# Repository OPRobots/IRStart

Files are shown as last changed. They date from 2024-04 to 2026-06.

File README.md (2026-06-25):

# IRStart

Mando y módulo para el arranque de nuestros robots usando el protocolo RC5.
Basado en: https://p1r.se/startmodule/ por lo que lo hemos hecho compatible
y con un funcionamiento muy similar para que sea apto para competir en la
RoboChallenge de Rumania.

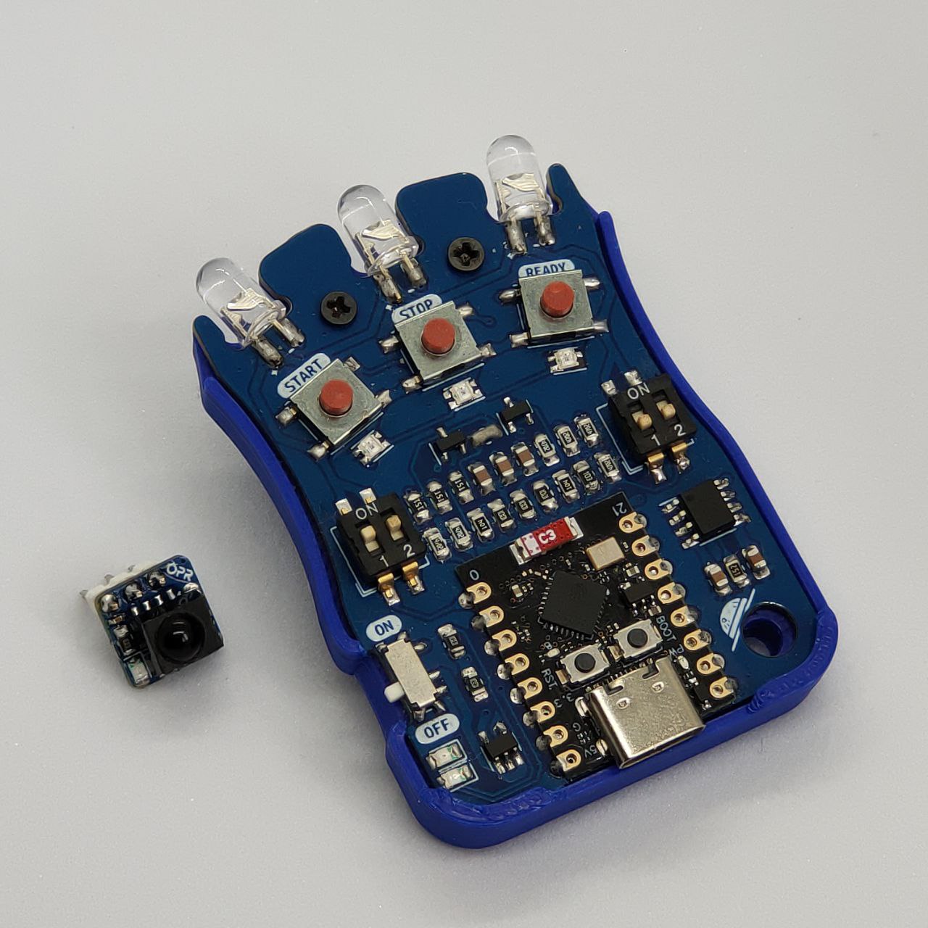
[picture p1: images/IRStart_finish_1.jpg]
IRStart - Diseño módulo


## ⚙️ Hardware

### Módulo
- ATTiny13 SMD SOIC-8
- Receptor IR TSOP4838
- LED azul SMD 0804
- 1 resistencia 220 Ω SMD 0804
- 1 condensador 104 (100 nF) SMD 0402

### Mando
- ESP32 C3 Super Mini
- 3 LEDs IR con MOSFETs (Start/Stop alta intensidad, Ready baja intensidad)
- DIP switch ×4 para configuración de robot (ID)
- NeoPixel RGB ×3 para indicación de estado
- Botones: Start, Stop, Ready, Mode
- Interruptor de encendido
- Módulo de carga de batería LiPo
- Batería LiPo 1S 500 mAh

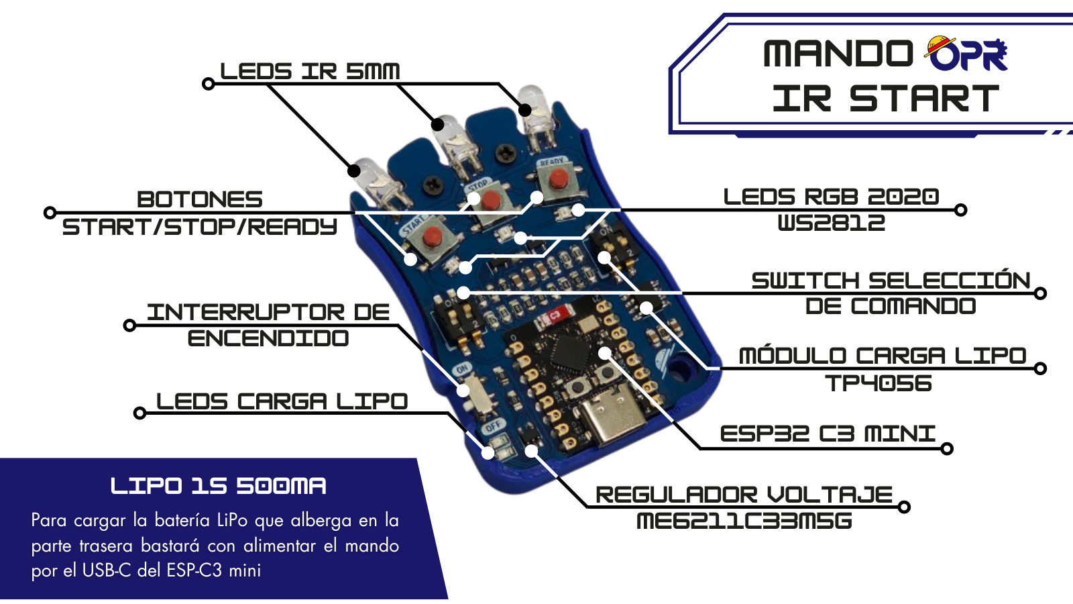
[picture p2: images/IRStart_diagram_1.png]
IRStart - Mando


## 💻 Software

- Programado con PlatformIO (Arduino framework)
- Firmware para módulo (ATtiny13/ATtiny85) y mando (ESP32-C3)
- **Protocolos IR**: RC5, NEC, SIRC
- **Modos**: IRSTART (competición) + IRMENU (control de menú remoto)
- **Frecuencia portadora**: 36 kHz (RC5) / 37 kHz (NEC, SIRC)
- **Debug**: Serial 115200 baud + patrones LED

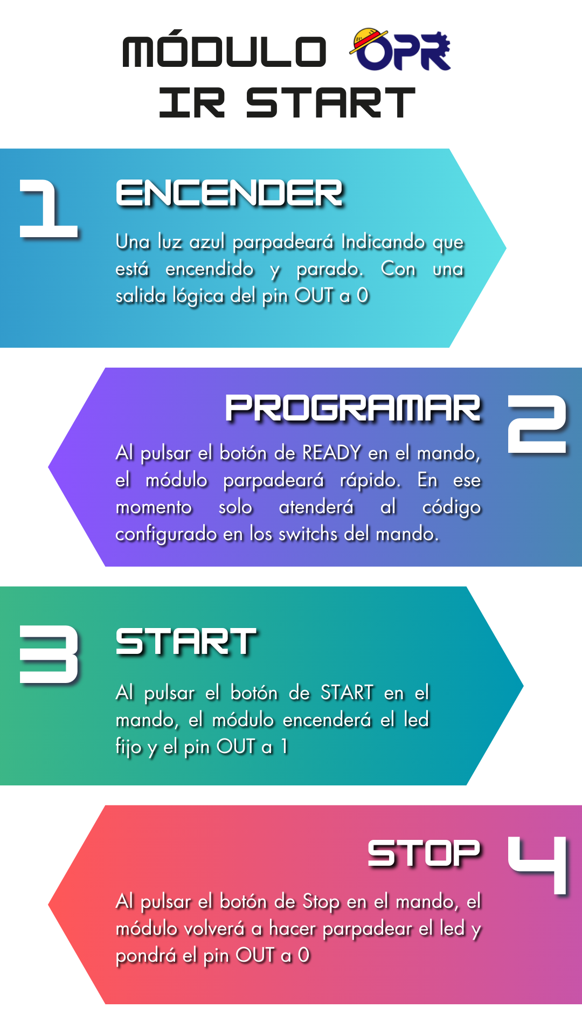
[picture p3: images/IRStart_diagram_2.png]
IRStart - Módulo


## 📚 Documentación

- [Hardware](docs/01-hardware.md) — MCUs, pinout, componentes, diseño 3D
- [Arquitectura Software](docs/02-software-architecture.md) — Bucles, ISRs, máquinas de estado
- [Protocolos IR](docs/03-ir-protocols.md) — RC5, NEC, SIRC: codificación y timing
- [Menú](docs/04-menu-system.md) — Modo IRMENU y navegación remota
- [Debug](docs/05-debug-system.md) — Salida serie y patrones LED
- [EEPROM](docs/06-storage.md) — EEPROM del ATtiny
- [Problemas Conocidos](docs/07-known-issues.md) — 10 issues (3 críticos)

## 🔧 Stack Tecnológico

| Componente | Tecnología |
|---|---|
| **Mando MCU** | ESP32-C3 (RISC-V 160 MHz) |
| **Módulo MCU** | ATtiny13/85 (AVR 8-bit) |
| **Framework** | Arduino |
| **Entorno** | PlatformIO |
| **Lenguaje** | C++11 |
| **Protocolos** | RC5, NEC, SIRC |

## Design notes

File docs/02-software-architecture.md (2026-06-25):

# Arquitectura Software

El sistema IRStart tiene dos arquitecturas independientes: el **mando**
(Remote, ESP32-C3) que emite códigos IR, y el **módulo** (Module,
ATtiny13/85) que los recibe y controla la señal de arranque/parada.

---

## Mando (Remote — ESP32-C3)

### Bucle Principal

```mermaid
flowchart TD
    A[Boot] --> B[init_components]
    B --> C{¿Botón pulsado en boot?}
    C -->|Start| D[Protocolo = RC5]
    C -->|Stop| E[Protocolo = NEC]
    C -->|Ready| F[Protocolo = SIRC]
    C -->|Ninguno| G[Protocolo = RC5 default]
    D --> H[init_ir]
    E --> H
    F --> H
    G --> H
    H --> I[Esperar liberación de botones]
    I --> J[Mostrar LEDs modo]
    J --> K[Loop]
    K --> L{¿Botón Ready?}
    L -->|Sí| M[Enviar Ready]
    L -->|No| N{¿Botón Start?}
    N -->|Sí| O[Enviar Start]
    N -->|No| P{¿Botón Stop?}
    P -->|Sí| Q[Enviar Stop]
    P -->|No| R{¿Botón Mode?}
    R -->|Sí| S[Cambiar modo]
    R -->|No| T[Actualizar LEDs según modo]
    M --> T
    O --> T
    Q --> T
    S --> T
    T --> K
```

### Secuencia de Boot

1. `init_components()` configura todos los pines (GPIO, NeoPixel, Serial)
2. Se detecta qué botón está pulsado al encender para seleccionar el protocolo
3. Se inicializa el protocolo IR con `init_ir()`
4. Se espera a que el usuario suelte todos los botones (LED parpadea)
5. Se muestran los colores de modo en los NeoPixels y se entra al bucle

| Protocolo | Botón en boot | Color Ready | Color Start | Color Stop |
|---|---|---|---|---|
| **RC5** | Start | Rojo | Verde | Azul |
| **NEC** | Stop | Rojo | Verde | Azul |
| **SIRC** | Ready | Rojo | Verde | Azul |

### Sistema de Modos

El mando tiene dos modos de operación:

| Modo | ID | Botón Start | Botón Stop | Botón Ready |
|---|----|---|---|---|
| **IRSTART** | 0 | Envía Start | Envía Stop | Prog/Ready |
| **IRMENU** | 1 | Menú Arriba | Menú Abajo | Menú Modo |

El cambio de modo se realiza con el botón Mode (GPIO 6) y es cíclico:
`(modo_actual + 1) % NUM_MODES`.

### Envío de comandos

Cada protocolo implementa su propia inicialización y funciones de envío:

| Función | RC5 | NEC | SIRC |
|---|-----|-----|---|
| **Init** | `rc5_init()` | `nec_init()` | `sirc_init()` |
| **Ready** | `rc5_send_prog()` | `nec_send_ready()` | `sirc_send_ready()` |
| **Start** | `rc5_send_start()` | `nec_send_start()` | `sirc_send_start()` |
| **Stop** | `rc5_send_stop()` | `nec_send_stop()` | `sirc_send_stop()` |

### Sistema de entrada

Todos los botones usan un debounce por software de 10 ms con doble lectura:

```cpp
bool get_btn_start() {
    bool state1 = digitalRead(BTN_START);
    delay(10);
    bool state2 = digitalRead(BTN_START);
    return state1 && state2;
}
```

El DIP switch de 4 posiciones se lee como un valor de 4 bits, desplazado 1
bit a la izquierda (`<< 1`), generando un ID de robot par entre 0 y 30.

---

## Módulo (Module — ATtiny13/85)

### Bucle Principal

```mermaid
flowchart TD
    A[Boot] --> B[init_pinout]
    B --> C[rc5_init]
    C --> D[Loop]
    D --> E{¿module_is_started?}
    E -->|Sí| F[LED ON fijo]
    E -->|No| G[LED parpadeando]
    F --> D
    G --> D
```

### ISR del Receptor IR

El módulo opera enteramente por interrupciones. El pin `PIN_IR` (PB1) se
configura con `attachInterrupt(CHANGE)` para detectar cada flanco (subida
y bajada) de la señal del TSOP4838.

| Parámetro | Valor |
|---|---|
| **Pin** | PB1 (digitalPinToInterrupt) |
| **Modo** | CHANGE (flanco de subida y bajada) |
| **ISR** | `rc5_isr()` |

### Cadena de procesamiento RC5

```
TSOP4838 → PIN_IR (CHANGE INT) → rc5_isr() → rc5_register() → rc5_decode_pulse()
    → rc5_decode_event() → (14 bits) → rc5_manage_command()
```

1. **`rc5_isr()`**: Lee el estado del pin IR y llama a `rc5_register()` con el
   trigger (RISING/FALLING)
2. **`rc5_register()`**: Calcula el tiempo transcurrido desde el último flanco
   y llama a `rc5_decode_pulse()` con ese `elapsed`. Incluye un
   `delayMicroseconds(100)` tras el cálculo
3. **`rc5_decode_pulse()`**: Clasifica el pulso como corto o largo según las
   constantes de timing, y llama a `rc5_decode_event()`
4. **`rc5_decode_event()`**: Máquina de estados de 4 estados para decodificar
   el código Manchester del protocolo RC5
5. **`rc5_manage_command()`**: Cuando se completan 14 bits, procesa el comando:
   - **Address PROG (0x0B)**: Programa un nuevo código de start/stop
   - **Address COMP (0x07)**: Compara con el código almacenado y ejecuta
   - **Default**: Comandos fijos 0x01 (start) y 0x02 (stop)

### Máquina de Estados RC5 (Receptor)

```mermaid
stateDiagram-v2
    [*] --> STATE_MID1
    STATE_MID1 --> STATE_MID0 : short space / long space
    STATE_MID0 --> STATE_MID0 : short pulse / long pulse
    STATE_MID0 --> STATE_MID1 : short space
    STATE_MID1 --> STATE_MID1 : long space / short pulse
    STATE_MID1 --> STATE_START1 : long pulse
    STATE_START1 --> STATE_MID0 : short space / long space
    STATE_START1 --> STATE_START0 : short pulse
    STATE_START0 --> STATE_START0 : long pulse / short pulse
    STATE_START0 --> STATE_MID1 : long space
```

> Basado en la implementación de [p1r.se/startmodule](https://p1r.se/startmodule/) con la información de [SB-Projects RC5 Protocol](https://www.sbprojects.net/knowledge/ir/rc5.php).

### Control de señal

| Función | Efecto |
|---|---|
| `module_start()` | `PIN_SIGNAL = HIGH`, `PIN_LED = HIGH`, `started = true` |
| `module_stop()` | `PIN_SIGNAL = LOW`, `PIN_LED = LOW`, `started = false` |
| `module_feedback()` | 5 parpadeos LED acelerados + pausa de 1.5 s |

El pin `PIN_SIGNAL` (PB0) es la salida física hacia el robot, y el LED (PB4)
refleja el estado de la señal.

---

## Compilación condicional

| Macro | Función |
|---|---|
| `PIO_FRAMEWORK_ARDUINO_ENABLE_CDC` | Habilita CDC Serial en ESP32-C3 (Remote) |

---

*Documento generado el 2025-06-25. Ver también [Hardware](01-hardware.md), [Protocolos IR](03-ir-protocols.md), [Problemas Conocidos](07-known-issues.md).*

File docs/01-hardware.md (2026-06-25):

# Hardware

El sistema IRStart se compone de dos dispositivos independientes: un **mando**
(Remote) basado en ESP32-C3 que emite señales infrarrojas con múltiples
protocolos, y un **módulo** (Module) basado en ATtiny que las recibe y actúa
como señal de arranque/parada para robots de competición.

---

## Mando (Remote)

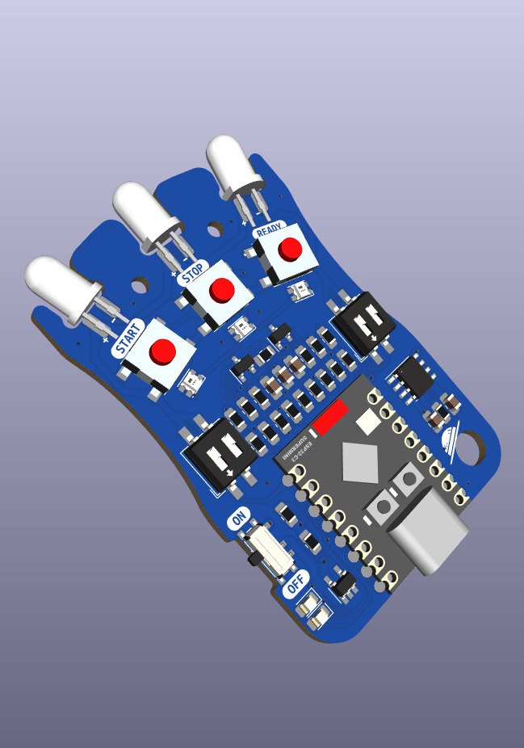
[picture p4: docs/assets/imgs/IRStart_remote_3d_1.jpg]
Remote 3D Model


### Microcontrolador

| Característica | Detalle |
|---|---|
| **Modelo** | Seeed XIAO ESP32C3 |
| **MCU** | ESP32-C3 (RISC-V 32 bits) |
| **Frecuencia** | 160 MHz |
| **Flash** | 4 MB |
| **RAM** | 400 KB SRAM |
| **Framework** | Arduino (ESP32 Core) |
| **Entorno** | PlatformIO |

### Componentes

| Componente | Modelo / Especificación | Cantidad |
|---|---|---|
| **LED IR (alta intensidad)** | MOSFET para Start/Stop | 2 |
| **LED IR (baja intensidad)** | MOSFET para Ready | 1 |
| **LED RGB** | NeoPixel WS2812B (×3) | 1 tira |
| **LED indicador** | LED onboard | 1 |
| **Botón Start** | Pulsador táctil | 1 |
| **Botón Stop** | Pulsador táctil | 1 |
| **Botón Ready** | Pulsador táctil | 1 |
| **Botón Modo** | Pulsador táctil | 1 |
| **DIP Switch** | 4 posiciones | 1 |
| **Interruptor** | Encendido principal | 1 |
| **Cargador de batería** | Módulo carga LiPo 1S | 1 |
| **Batería** | LiPo 1S 500 mAh | 1 |

### Pinout

| Pin | Periférico | Función |
|-----|---|---|
| **GPIO 8** | LED | LED indicador onboard |
| **GPIO 5** | NeoPixel | Tira de 3 LEDs RGB |
| **GPIO 2** | BAT_ANALOG | Lectura de batería (definido, sin usar) |
| **GPIO 4** | IR_CMD / LEDC Ch.0 | LED IR de comandos (Start/Stop) |
| **GPIO 7** | IR_PROG / LEDC Ch.1 | LED IR de programación (Ready) |
| **GPIO 21** | BTN_START | Botón de inicio |
| **GPIO 20** | BTN_STOP | Botón de parada |
| **GPIO 10** | BTN_READY | Botón de preparado |
| **GPIO 6** | BTN_MODE | Botón de cambio de modo |
| **GPIO 0** | DIP_SW_0 | DIP switch bit 0 (LSB) |
| **GPIO 1** | DIP_SW_1 | DIP switch bit 1 |
| **GPIO 2** | DIP_SW_2 | DIP switch bit 2 |
| **GPIO 3** | DIP_SW_3 | DIP switch bit 3 (MSB) |

> **Nota**: Los pines de los DIP switches usan GPIO 0–3. GPIO 2 está compartido
> con `BAT_ANALOG`, pero la funcionalidad de lectura de batería no está
> implementada.

### LEDs IR y MOSFETs

El mando utiliza dos canales PWM independientes para los LEDs infrarrojos:

| Canal | GPIO | LEDC Ch. | Propósito | Intensidad |
|---|---|---|---|---|
| **CMD** | GPIO 4 | 0 | Start / Stop | Alta (MOSFET dedicado) |
| **PROG** | GPIO 7 | 1 | Ready / Programación | Baja (MOSFET dedicado) |

Cada canal se configura con PWM de 10 bits de resolución. La frecuencia
portadora varía según el protocolo: **36 kHz** para RC5 y **37–40 kHz** para
NEC y SIRC.

---

## Módulo (Module)

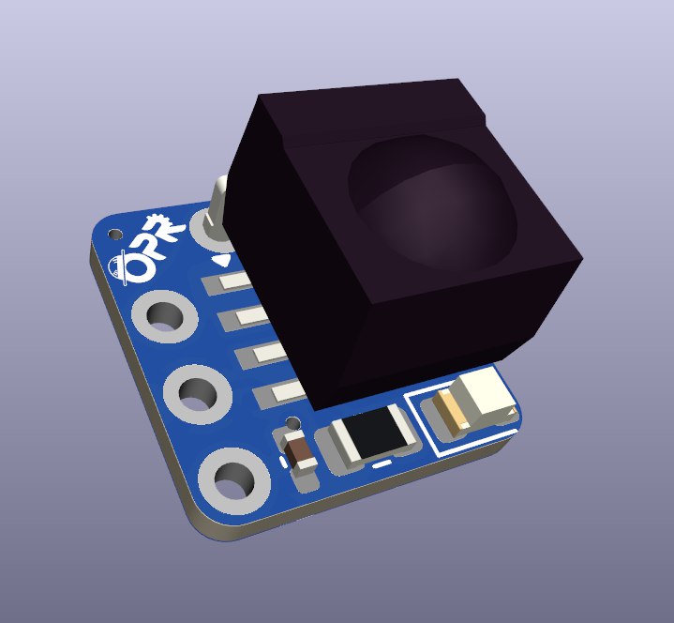
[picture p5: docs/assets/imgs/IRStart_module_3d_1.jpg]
Module 3D Model


### Microcontrolador

| Característica | Detalle |
|---|---|
| **Modelo** | ATtiny13 / ATtiny85 |
| **Arquitectura** | AVR 8 bits |
| **Frecuencia** | 1.2 MHz (default) / 9.6 MHz (internal) |
| **Flash** | 1 KB (ATtiny13) / 8 KB (ATtiny85) |
| **RAM** | 64 B (ATtiny13) / 512 B (ATtiny85) |
| **EEPROM** | 64 B (ATtiny13) / 512 B (ATtiny85) |
| **Framework** | Arduino (ATTinyCore) |
| **Entorno** | PlatformIO |

El `platformio.ini` soporta tanto **ATtiny13** como **ATtiny85**, con entornos
de programación directa y vía ArduinoISP.

### Componentes

| Componente | Modelo / Especificación | Cantidad |
|---|---|---|
| **Receptor IR** | TSOP4838 | 1 |
| **LED azul** | SMD 0804 | 1 |
| **Resistencia** | 220 Ω SMD 0804 | 1 |
| **Condensador** | 104 (100 nF) SMD 0402 | 1 |

### Pinout

| Pin | Periférico | Función |
|-----|---|---|
| **PB0** | PIN_SIGNAL | Salida de señal Start/Stop |
| **PB1** | PIN_IR | Receptor IR (TSOP4838) con interrupción CHANGE |
| **PB2** | PIN_RESET | Reset de EEPROM (definido, código comentado) |
| **PB4** | PIN_LED | LED indicador de estado |

> **Nota**: PB2 (Pin 2) está definido como `PIN_RESET` para restaurar la EEPROM
> a valores de fábrica, pero tanto la lectura del pin como la función
> `rc5_reset_eeprom()` están comentadas en el código.

### Diseño mecánico

| Característica | Detalle |
|---|---|
| **PCB** | Diseño personalizado (SMD) |
| **Modelo 3D** | [`3d_model/Module/IRStart - Module.stl`](../3d_model/Module/IRStart%20-%20Module.stl) |
| **STEP** | [`3d_model/Module/IRStart - Module.step`](../3d_model/Module/IRStart%20-%20Module.step) |
| **Carcasa Remote** | [`3d_model/Remote/IRstart - Remote PCB.step`](../3d_model/Remote/IRstart%20-%20Remote%20PCB.step) |

---

## Diagrama del Sistema

```mermaid
flowchart TD
    Remote[ESP32-C3 Mando]
    Module[ATtiny13/85 Módulo]

    subgraph "Mando (Remote)"
        BTN[Start/Stop/Ready/Mode]
        DIP[DIP Switch ×4]
        NeoPixel[NeoPixel ×3 RGB]
        LED_C[LED IR CMD]
        LED_P[LED IR PROG]
        ESP[ESP32-C3]
        BATT[LiPo 1S 500mAh]

        BTN --> ESP
        DIP --> ESP
        ESP --> NeoPixel
        ESP --> LED_C
        ESP --> LED_P
        BATT --> ESP
    end

    subgraph "Módulo (Module)"
        IR_RX[TSOP4838]
        ATTINY[ATtiny13/85]
        LED_M[LED Azul]
        SIGNAL[Señal Start/Stop]

        IR_RX -->|CHANGE INT| ATTINY
        ATTINY --> LED_M
        ATTINY --> SIGNAL
    end

    LED_C -->|RC5/NEC/SIRC| IR_RX
    LED_P -->|RC5 Prog| IR_RX
    SIGNAL -->|GPIO| Robot
```

---

*Documento generado el 2025-06-25. Ver también [Arquitectura Software](02-software-architecture.md), [Protocolos IR](03-ir-protocols.md).*

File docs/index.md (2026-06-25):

# IRStart

Sistema de arranque por infrarrojos para competiciones de robótica. Compuesto
por un **mando** inalámbrico multi-protocolo (RC5, NEC, SIRC) y un **módulo**
receptor ultracompacto compatible con el estándar de la RoboChallenge Romania.

IRStart - Mando y Módulo

---

## ⚙️ Hardware

| Característica | Detalle |
|---|---|
| **Mando MCU** | ESP32-C3 (Seeed XIAO) @ 160 MHz |
| **Módulo MCU** | ATtiny13 / ATtiny85 @ 1.2 MHz |
| **Emisor IR** | 3× LEDs IR con MOSFETs |
| **Receptor IR** | TSOP4838 |
| **Batería** | LiPo 1S 500 mAh con cargador integrado |
| **Indicadores** | NeoPixel RGB ×3 + LED onboard |

IRStart - Mando

## 💻 Software

| Componente | Detalle |
|---|---|
| **Framework** | Arduino |
| **Entorno** | PlatformIO |
| **Protocolos IR** | RC5, NEC, SIRC |
| **Modos** | IRSTART (competición) + IRMENU (control menú) |
| **Debug** | Serial 115200 baud + patrones LED |

IRStart - Diagrama

## 📚 Documentación

- [Hardware](01-hardware.md) — MCUs, pinout, componentes, diseño mecánico
- [Arquitectura Software](02-software-architecture.md) — Bucles principales, ISRs, máquinas de estado
- [Protocolos IR](03-ir-protocols.md) — RC5, NEC, SIRC: codificación, temporización, implementación
- [Sistema de Menú](04-menu-system.md) — Modo IRMENU, navegación remota
- [Sistema de Debug](05-debug-system.md) — Salida serie, patrones LED, telemetría
- [EEPROM](06-storage.md) — EEPROM del ATtiny, comandos programados
- [Problemas Conocidos](07-known-issues.md) — 10 issues documentados (3 críticos)

---

## 🔧 Stack Tecnológico

| Capa | Tecnología |
|---|---|
| **Mando MCU** | ESP32-C3 (RISC-V) |
| **Módulo MCU** | ATtiny13/85 (AVR 8-bit) |
| **Framework** | Arduino |
| **Entorno** | PlatformIO |
| **Lenguaje** | C++11 |
| **Protocolos** | RC5, NEC, SIRC |
| **Documentación** | MkDocs Material |

---

## 🎥 Vídeos

*No disponibles.*

---

*Documento generado el 2025-06-25. Ver también [Hardware](01-hardware.md).*

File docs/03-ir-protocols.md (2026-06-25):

# Protocolos IR

El mando implementa tres protocolos infrarrojos que se seleccionan durante el
arranque. Cada protocolo tiene su propia codificación, temporización y
frecuencia portadora. El módulo receptor solo decodifica **RC5**.

---

## Comparativa de Protocolos

| Característica | RC5 | NEC | SIRC |
|---|-----|-----|---|
| **Frecuencia portadora** | 36 kHz | 37 kHz | 37 kHz |
| **Codificación** | Manchester (bi-fase) | Pulso-espacio | Pulso-espacio |
| **Bits de comando** | 6 | 8 | 7 |
| **Bits de dirección** | 5 | 8 | 5 |
| **Bit de toggle** | Sí (1 bit) | No | No |
| **Repetición** | Reenvío completo | Código de repetición especial | Reenvío completo |
| **Fin de trama** | Liberación de portadora | Pulso final 560 µs | Liberación de portadora |
| **Tiempo entre comandos** | — | 110 ms | 45 ms |
| **Usado por módulo** | ✅ Sí | ❌ No | ❌ No |

---

## RC5 (Remote Control 5)

Protocolo principal del sistema, desarrollado originalmente por Philips.
El mando lo usa en **modo IRSTART e IRMENU**.

### Formato de trama

```
| S1 | S2 | T | A4 | A3 | A2 | A1 | A0 | C5 | C4 | C3 | C2 | C1 | C0 |
|   Start  | Toggle |    Dirección (5 bits)    |     Comando (6 bits)       |
```

| Campo | Bits | Posición | Descripción |
|---|---|---|---|
| **Start** | 2 | 13–12 | Bits de inicio (S1=1, S2=1) |
| **Toggle** | 1 | 11 | Bit de alternancia (cambia cada pulsación) |
| **Address** | 5 | 10–6 | Dirección del dispositivo |
| **Command** | 6 | 5–0 | Código del comando |

### Codificación Manchester

En RC5 cada bit se codifica en dos medios bits:
- **Bit 1**: portadora OFF → portadora ON (flanco de bajada en el medio)
- **Bit 0**: portadora ON → portadora OFF (flanco de subida en el medio)

Cada medio bit tiene una duración nominal de **889 µs** (1/36 kHz × 32 ciclos).

### Temporización del Receptor

El receptor usa la siguientes ventanas de detección (en µs):

| Pulso | Mínimo | Máximo |
|---|---|---|
| **Corto** | 444 µs | 1333 µs |
| **Largo** | 1334 µs | 2222 µs |

> **⚠️ Advertencia**: El gap entre corto y largo es de solo 1 µs
> (MAX_SHORT = 1333, MIN_LONG = 1334). Esto no deja histéresis y puede
> causar detecciones erróneas con tolerancia de reloj. Ver
> [SW-04](07-known-issues.md#sw-04).

### Direcciones y Comandos

| Dirección | Uso | Comandos |
|---|-----|---|
| **0x07** (COMP) | Competición — Start/Stop | `0x01` = Stop, `0x02` = Start + ID robot |
| **0x0B** (PROG) | Programación — Configurar ID | `0x01` + ID = Programar |
| **0x1B** (IRMENU) | Control de menú remoto | `0x0C` = Mode, `0x0D` = Up, `0x0E` = Down |

### ID de Robot

El DIP switch de 4 bits genera un ID entre 0 y 30 (par, `dip << 1`).
Cuando el ID es 0, se usan comandos fijos; cuando es distinto de 0, se
codifica en los bits superiores del comando:

- **Start con ID ≠ 0**: `(id << 1) | 0b00000001` → bit bajo = 1
- **Stop con ID ≠ 0**: `(id << 1) & 0b11111110` → bit bajo = 0

### Implementación en el Mando

[`rc5.cpp:1-139`](../source_code/Remote/src/rc5.cpp)

| Función | Dirección | Comando | Canal PWM |
|---|---|---|---|
| `rc5_send_prog()` | 0x0B | 0x01 (id=0) / `id<<1` | IR_PROG (Ch.1) |
| `rc5_send_start()` | 0x07 | 0x02 (id=0) / `(id<<1)\|1` | IR_CMD (Ch.0) |
| `rc5_send_stop()` | 0x07 | 0x01 (id=0) / `(id<<1)&0xFE` | IR_CMD (Ch.0) |
| `rc5_send_menu_mode()` | 0x1B | 0x0C | IR_CMD (Ch.0) |
| `rc5_send_menu_up()` | 0x1B | 0x0D | IR_CMD (Ch.0) |
| `rc5_send_menu_down()` | 0x1B | 0x0E | IR_CMD (Ch.0) |

| Parámetro | Valor |
|---|---|
| **PWM freq** | 36 kHz |
| **Resolución PWM** | 10 bits (0–1023) |
| **Duty cycle** | 1/5 (≈205) |
| **Duración medio bit** | 889 µs |

### Implementación en el Módulo

[`rc5.cpp:1-121`](../source_code/Module/src/rc5.cpp)

| Constante | Valor |
|---|---|
| `MIN_SHORT` | 444 µs |
| `MAX_SHORT` | 1333 µs |
| `MIN_LONG` | 1334 µs |
| `MAX_LONG` | 2222 µs |

---

## NEC

Protocolo desarrollado por NEC Corporation, usado en muchos mandos de consumo.

### Formato de trama

```
| Start Burst | Address | ~Address | Command | ~Command | Stop Bit |
|   9 ms ON   |  8 bits |  8 bits  |  8 bits |  8 bits  | 560 µs   |
|  4.5 ms OFF |         | (invert) |         | (invert) |          |
```

| Campo | Descripción |
|---|---|
| **Start Burst** | 9 ms portadora ON + 4.5 ms OFF |
| **Address** | Dirección de 8 bits (0x01 fijo) |
| **~Address** | Dirección invertida (verificación) |
| **Command** | Comando de 8 bits |
| **~Command** | Comando invertido (verificación) |
| **Stop Bit** | Pulso final de 560 µs |

### Codificación de bits

| Bit | Portadora ON | Espacio |
|-----|---|---|
| **0** | 560 µs | 560 µs |
| **1** | 560 µs | 1690 µs |

### Código de Repetición

Para repeticiones (botón mantenido pulsado), se envía un código especial:
- 9 ms portadora ON + 2.25 ms OFF + 560 µs ON

### Implementación

[`nec.cpp:1-134`](../source_code/Remote/src/nec.cpp)

| Parámetro | Valor |
|---|---|
| **PWM freq** | 37 kHz |
| **Duty cycle** | 1/3 (≈341) |
| **Tiempo entre comandos** | 110 ms |
| **Address** | 0x01 |
| **CMD_READY** | 0x00 |
| **CMD_START** | 0x01 |
| **CMD_STOP** | 0x02 |

---

## SIRC (Sony Infrared Remote Control)

Protocolo de Sony, usado en productos de consumo (TV, audio).

### Formato de trama

```
| Start Burst | Command (7 bits) | Address (5 bits) |
|  2.4 ms ON  |  LSB primero     |  LSB primero     |
|  0.6 ms OFF |                   |                  |
```

| Campo | Descripción |
|---|---|
| **Start Burst** | 2.4 ms portadora ON + 0.6 ms OFF |
| **Command** | 7 bits, LSB primero |
| **Address** | 5 bits, LSB primero |

### Codificación de bits

| Bit | Portadora ON | Espacio |
|-----|---|---|
| **0** | 600 µs | 600 µs |
| **1** | 1200 µs | 600 µs |

> **Nota**: En SIRC, los bits se envían en orden **LSB primero** (a diferencia
> de NEC y RC5 que usan MSB primero). Ver el bucle `for (int i = 0; i < 7; i++)`
> en la implementación.

### Implementación

[`sirc.cpp:1-95`](../source_code/Remote/src/sirc.cpp)

| Parámetro | Valor |
|---|---|
| **PWM freq** | 37 kHz |
| **Duty cycle** | 1/3 (≈341) |
| **Tiempo entre comandos** | 45 ms |
| **Address** | 0x01 |
| **CMD_READY** | 0x00 |
| **CMD_START** | 0x01 |
| **CMD_STOP** | 0x02 |

---

## Flujo de Comunicación

```mermaid
sequenceDiagram
    participant User
    participant Remote as Mando (ESP32-C3)
    participant Module as Módulo (ATtiny13)
    participant Robot

    Note over User,Robot: Fase de Programación (RC5)
    User->>Remote: Pulsa Ready
    Remote->>Module: RC5 ADDR_PROG + ID (IR_PROG)
    Module->>Module: Guarda ID en EEPROM
    Module->>Module: Feedback LED ×5

    Note over User,Robot: Fase de Competición (RC5/NEC/SIRC)
    User->>Remote: Pulsa Start
    Remote->>Module: Protocolo + CMD_START (IR_CMD)
    Module->>Module: Compara con EEPROM
    Module->>Robot: PIN_SIGNAL = HIGH

    User->>Remote: Pulsa Stop
    Remote->>Module: Protocolo + CMD_STOP (IR_CMD)
    Module->>Robot: PIN_SIGNAL = LOW
```

---

*Documento generado el 2025-06-25. Ver también [Arquitectura Software](02-software-architecture.md), [Hardware](01-hardware.md), [Problemas Conocidos](07-known-issues.md).*

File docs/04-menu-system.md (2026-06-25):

# Sistema de Menú

El mando incorpora un sistema de menú IR para control remoto de robots
compatibles (modo **IRMENU**). Este modo es adicional al modo principal de
arranque (IRSTART) y permite navegar por menús de configuración del robot
mediante infrarrojos.

---

## Modos de Operación

El sistema tiene dos modos, ciclables con el botón Mode:

```mermaid
stateDiagram-v2
    [*] --> IRSTART
    IRSTART --> IRMENU : Botón Mode
    IRMENU --> IRSTART : Botón Mode
```

| Modo | ID | Función |
|---|----|---|
| **IRSTART** | 0 | Arranque/parada de competición |
| **IRMENU** | 1 | Navegación por menús del robot |

## Indicación Visual

Los NeoPixels indican el modo activo:

| Modo | NeoPixel 0 (Ready) | NeoPixel 1 (Start) | NeoPixel 2 (Stop) |
|---|---|---|---|
| **IRSTART** | Verde (G=50) | Rojo (R=50) | Magenta (R=50, B=50) |
| **IRMENU** | Apagado | Apagado | Azul (B=50) |

## Mapeo de Botones

En modo IRMENU, los botones cambian de función respecto al modo IRSTART:

| Botón | Modo IRSTART | Modo IRMENU |
|---|---|---|
| **Ready** | Programar ID | Menú Modo |
| **Start** | Iniciar | Menú Arriba |
| **Stop** | Parar | Menú Abajo |

## Protocolo

El modo IRMENU **solo funciona con el protocolo RC5**. Si se seleccionó NEC
o SIRC al arrancar, el mando no enviará comandos de menú (en su lugar,
`error_led()`).

| Comando | Dirección RC5 | Comando RC5 | Función |
|---|---|---|---|
| Menú Modo | `0x1B` (27) | `0x0C` (12) | Cambiar modo/seleccionar |
| Menú Arriba | `0x1B` (27) | `0x0D` (13) | Navegar arriba |
| Menú Abajo | `0x1B` (27) | `0x0E` (14) | Navegar abajo |

### Implementación

[`rc5.cpp:120-139`](../source_code/Remote/src/rc5.cpp)

```cpp
void rc5_send_menu_mode() {
    set_led(true);
    send_packet(IR_CMD_PWM, ADDR_IRMENU, CMD_IRMENU_MODE);
    set_led(false);
    delay(30);
}
```

---

## Flujo de Navegación

```mermaid
sequenceDiagram
    participant User
    participant Remote as Mando
    participant Robot

    Note over User,Robot: Modo IRMENU (RC5)
    User->>Remote: Pulsa Mode (cambia a IRMENU)
    Remote->>Remote: NeoPixel → Azul

    User->>Remote: Pulsa Ready
    Remote->>Robot: RC5 ADDR=0x1B CMD=0x0C (Mode)

    User->>Remote: Pulsa Start
    Remote->>Robot: RC5 ADDR=0x1B CMD=0x0D (Up)

    User->>Remote: Pulsa Stop
    Remote->>Robot: RC5 ADDR=0x1B CMD=0x0E (Down)
```

---

*Documento generado el 2025-06-25. Ver también [Protocolos IR](03-ir-protocols.md), [Arquitectura Software](02-software-architecture.md).*

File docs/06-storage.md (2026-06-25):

# EEPROM

El sistema IRStart utiliza la EEPROM interna del microcontrolador ATtiny en el
módulo para almacenar de forma persistente los comandos RC5 programados durante
la fase de pairing.

---

## Medio de Almacenamiento

| Característica | Detalle |
|---|---|
| **Tipo** | EEPROM interna del ATtiny |
| **Capacidad** | 64 B (ATtiny13) / 512 B (ATtiny85) |
| **Tecnología** | EEPROM on-chip AVR |
| **Librería** | `EEPROM.h` (Arduino) |

## Layout de Datos

| Offset | Tamaño | Campo | Descripción |
|---|---|---|---|
| `0x00` | 1 B | `EEPROM_ADDR_RC5_START` | Comando START programado |
| `0x10` | 1 B | `EEPROM_ADDR_RC5_STOP` | Comando STOP programado |

> **Nota**: Las direcciones están separadas por 16 bytes (`EEPROM_ADDR_RC5_START = 0`,
> `EEPROM_ADDR_RC5_STOP = 16`), aunque cada valor ocupa solo 1 byte. Esto deja
> espacio para expansión futura de datos de configuración.

## Operaciones

### Inicialización

[`rc5.cpp:85-88`](../source_code/Module/src/rc5.cpp)

```cpp
void rc5_init() {
    rc5_stored_data[DATA_START] = EEPROM.read(EEPROM_ADDR_RC5_START);
    rc5_stored_data[DATA_STOP] = EEPROM.read(EEPROM_ADDR_RC5_STOP);
}
```

Al arrancar, se cargan los comandos almacenados en un array en RAM
(`rc5_stored_data[2]`).

### Programación (Escritura)

[`rc5.cpp:22-50`](../source_code/Module/src/rc5.cpp)

Cuando el módulo recibe un comando con dirección `ADDRESS_PROG` (0x0B):

1. `command` → `rc5_stored_data[DATA_STOP]`
2. `command + 1` → `rc5_stored_data[DATA_START]`
3. Se escribe en EEPROM con `EEPROM.write()`
4. Se ejecuta `module_feedback()` para confirmar

| Condición | Comando STOP guardado | Comando START guardado |
|---|---|---|
| `id == 0` | `command` (del mando) | `command + 1` |
| `id != 0` | `(id << 1) & 0xFE` | `(id << 1) \| 1` |

### Verificación (Lectura)

En cada comando con dirección `ADDRESS_COMP` (0x07), el módulo compara el
comando recibido con los valores almacenados en RAM:

```cpp
if (command == rc5_stored_data[DATA_START]) {
    module_start();
} else if (command == rc5_stored_data[DATA_STOP]) {
    module_stop();
}
```

## Mecanismo de Integridad

| Mecanismo | Detalle |
|---|---|
| **Checksum** | ❌ No implementado |
| **Validación** | ❌ No se validan los datos al cargar |
| **Valores por defecto** | ❌ No se detecta EEPROM virgen (0xFF) |
| **Copia de seguridad** | ❌ Sin redundancia |

> **⚠️ Advertencia**: No hay verificación de integridad de los datos en EEPROM.
> Si la EEPROM está sin inicializar (valores 0xFF), los comandos no
> coincidirán con ningún código RC5 válido (los comandos RC5 son de 6 bits,
> máximo 0x3F). Esto actúa como protección implícita, pero no se notifica al
> usuario. Ver [EE-01](07-known-issues.md#ee-01).

## Reset de EEPROM

Existe código comentado para restaurar la EEPROM a valores por defecto:

[`rc5.cpp:90-96`](../source_code/Module/src/rc5.cpp) (comentado)

```cpp
// void rc5_reset_eeprom() {
//     EEPROM.write(EEPROM_ADDR_RC5_START, 0);
//     EEPROM.write(EEPROM_ADDR_RC5_STOP, 0);
//     rc5_init();
//     module_feedback();
// }
```

[`main.cpp:23-25`](../source_code/Module/src/main.cpp) (comentado)

```cpp
// if (!digitalRead(PIN_RESET)) {
//     rc5_reset_eeprom();
// }
```

El pin `PIN_RESET` (PB2) y la lógica de reset están definidos en [`pinout.h`](../source_code/Module/include/pinout.h#L7) pero no implementados.

---

*Documento generado el 2025-06-25. Ver también [Protocolos IR](03-ir-protocols.md), [Arquitectura Software](02-software-architecture.md), [Problemas Conocidos](07-known-issues.md).*

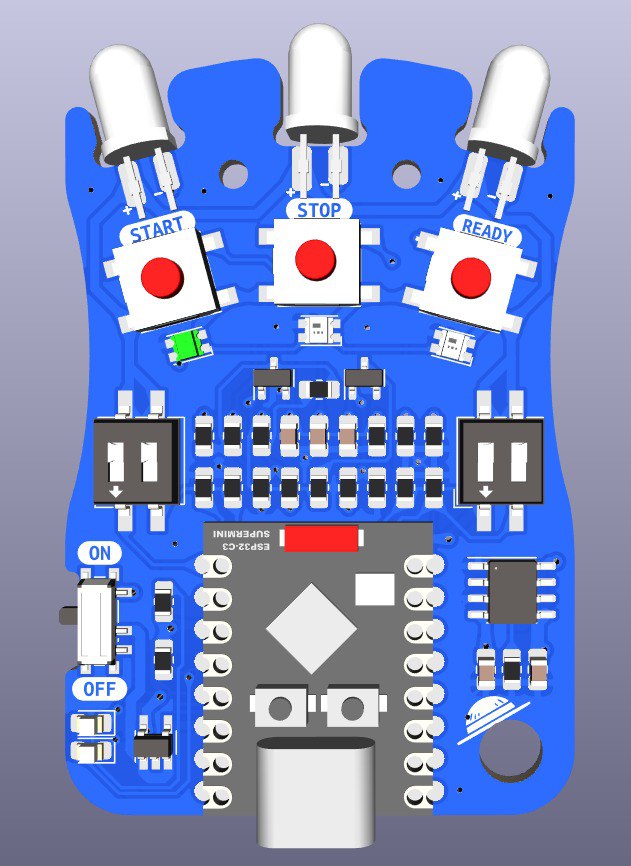
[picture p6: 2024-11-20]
images/IRStart_remote_3d_2.jpg

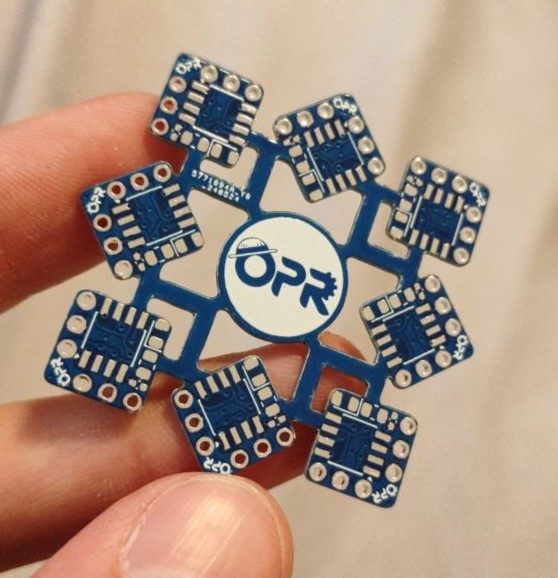
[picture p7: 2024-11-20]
images/IRStart_modules_pcb_1.jpg

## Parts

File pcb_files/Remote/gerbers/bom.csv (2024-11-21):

Designator | Footprint | Quantity | Value | LCSC Part #
BT1 | Leds_IR_Remote | 1 | Battery
BTN1, BTN2, BTN3 | SW_Push_1P1T_NO_6x6mm_H9.5mm | 3 | ~
BTN4 | SW_SPST_B3U-1000P | 1 | ~
C1, C2, C3 | 0805 | 3 | 0.1uF
C4, C5 | 0805 | 2 | 10uF
D1, D2 | 0805 | 2 | LED
ESP1 | ESP32_supermini | 1 | ~
LDO1 | SOT-23-5_HandSoldering | 1 | ~
LED1, LED2, LED3 | Leds_IR_Remote | 3 | ~
MOSFET1, MOSFET2 | SOT-23 | 2 | AO3414A
NEO1, NEO2, NEO3 | LED_WS2812B_2.0x2.0mm | 3 | ~
R1, R2, R3 | 0805 | 3 | 10
R10, R15, R4, R5, R8 | 0805 | 5 | 1K
R11, R12, R9 | 0805 | 3 | 100K
R13, R14, R16, R17, R6, R7 | 0805 | 6 | 47K
R18 | 0805 | 1 | 1K5
R19 | 0805 | 1 | 27k
R20 | 0805 | 1 | 10k
SW1, SW2 | SW_DIP_SPSTx02_Slide_6.7x6.64mm_W8.61mm_P2.54mm_LowProfile | 2 | SW_DIP_x02
SW3 | SW_SPDT_PCM12 | 1 | SW_DPDT_x2
TP4056 | SOP-8_3.9x4.9mm_P1.27mm | 1 | ~

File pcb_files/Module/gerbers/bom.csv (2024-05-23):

Designator | Footprint | Quantity | Value | LCSC Part #
C1 | 0402 | 1 | C
D1 | 0805 | 1 | LED
PROGRAM1 | Program_pads | 1 | Conn_01x06_Socket
R1 | 0805 | 1 | 1K
SUPPLY/OUTPUT1 | PinSocket_1x03_P2.54mm_Vertical | 1 | Conn_01x03_Socket
U1 | SOP8 | 1 | ATtiny13A-S
U2 | Vishay_MOLD-3Pin | 1 | TSOP45xx

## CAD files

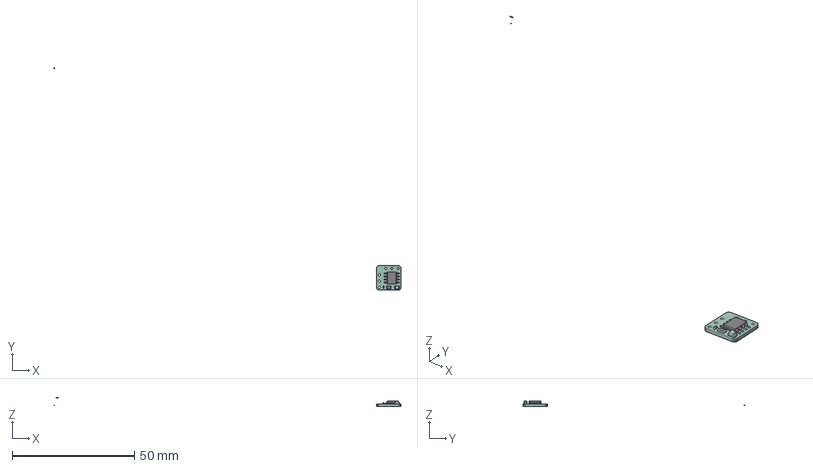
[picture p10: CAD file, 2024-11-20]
3d_model/Module/IRStart - Module.step
142.0 x 90.9 x 3.59 mm
SSOP-8_3.9x5.05mm_P1.27mm
PCB

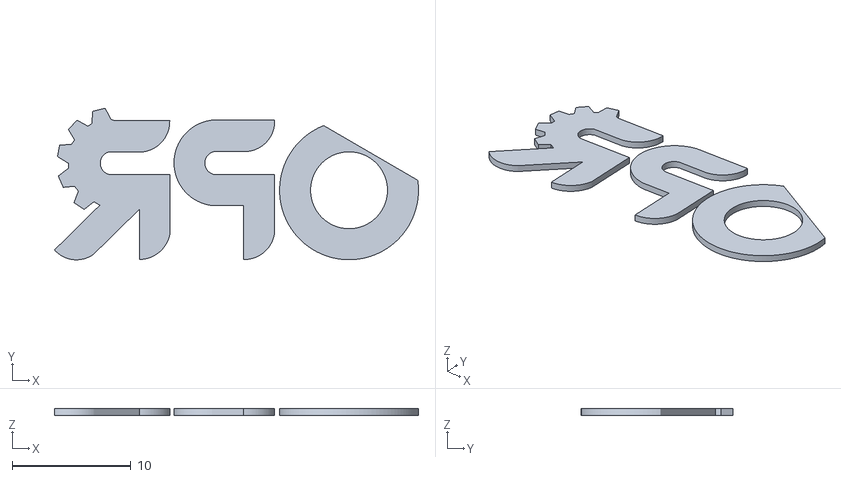
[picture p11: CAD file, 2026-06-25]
3d_model/Remote/IRStart - Remote case with Logo round/IRStart Remote - Multicolor 3.stl
30.6 x 12.8 x 0.568

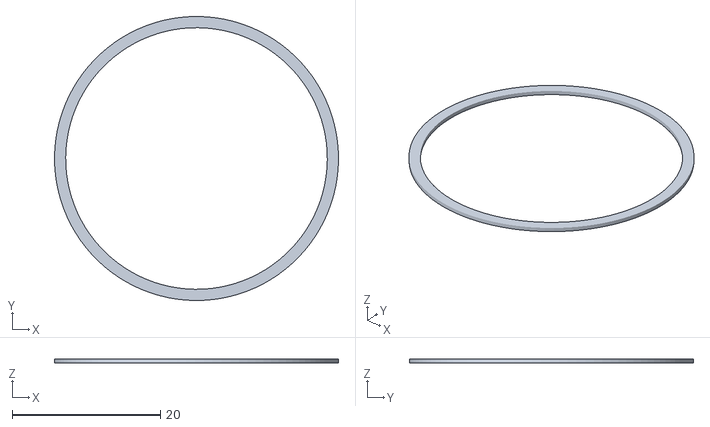
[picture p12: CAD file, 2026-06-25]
3d_model/Remote/IRStart - Remote case with Logo/IRStart Remote - Multicolor 2.stl
38.3 x 38.3 x 0.583

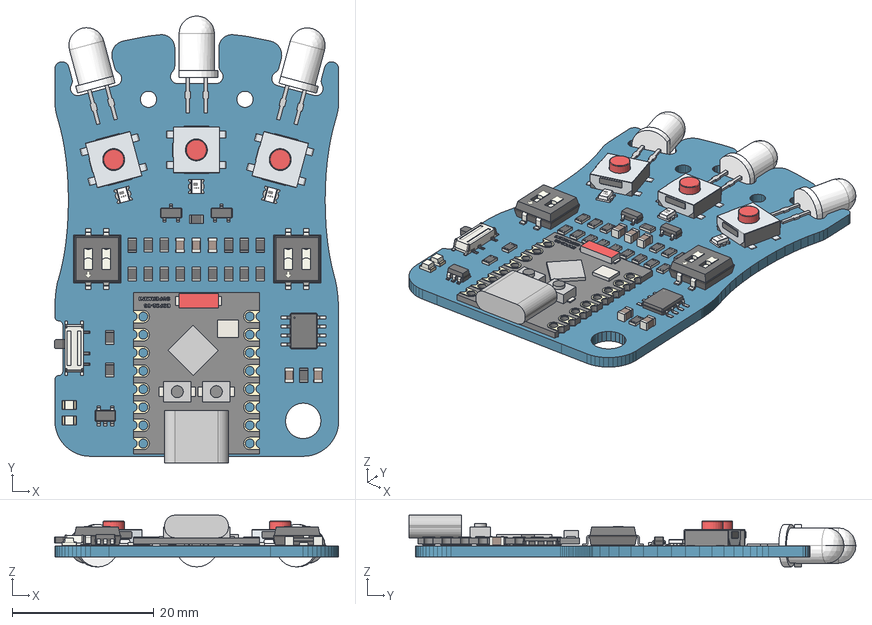
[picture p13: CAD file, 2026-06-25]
3d_model/Remote/IRstart - Remote PCB.step
40.1 x 63.0 x 7.30 mm
PCB

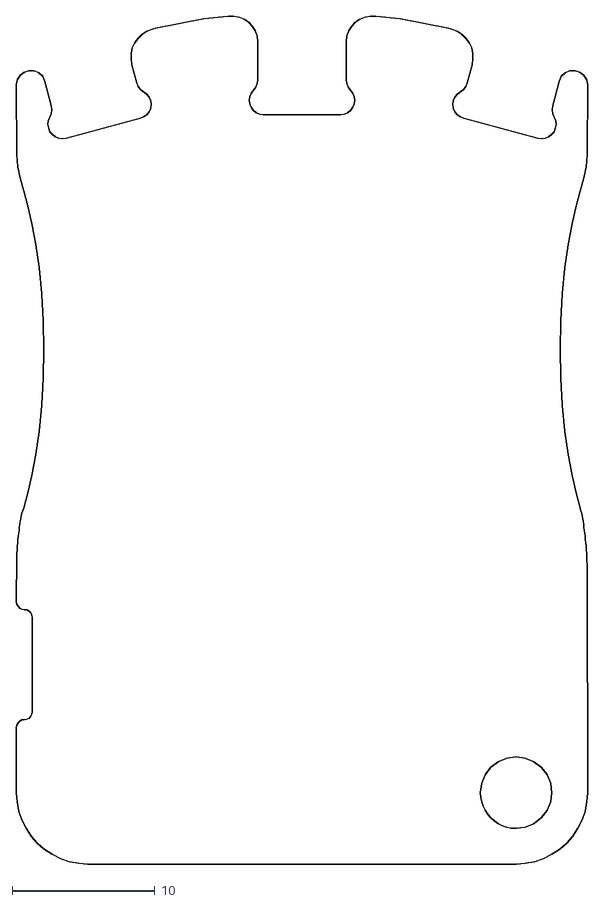
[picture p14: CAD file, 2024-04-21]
3d_model/Remote/sketchup/IRstart - Remote.dxf
40.0 x 59.4

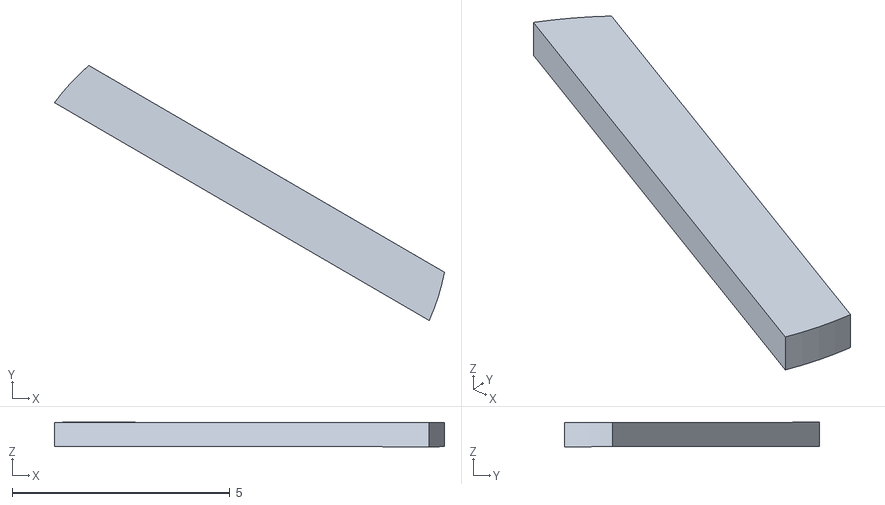
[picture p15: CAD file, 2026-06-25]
3d_model/Remote/IRStart - Remote case with Logo round/IRStart Remote - Multicolor 4.stl
8.96 x 5.86 x 0.564

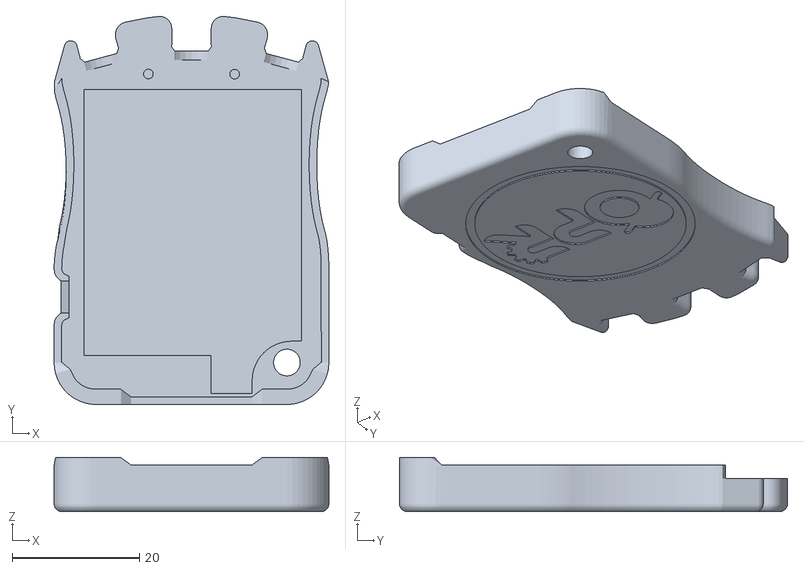
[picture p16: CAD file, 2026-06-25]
3d_model/Remote/IRStart - Remote case with Logo/IRStart Remote - Multicolor 1.stl
43.2 x 61.0 x 8.50

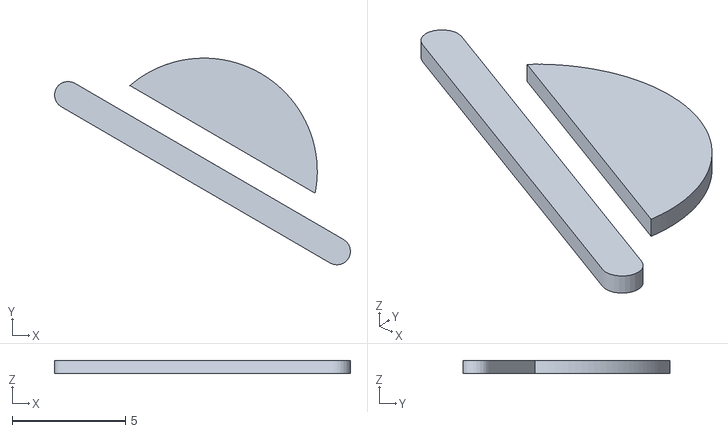
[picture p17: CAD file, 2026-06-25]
3d_model/Remote/IRStart - Remote case with Logo round/IRStart Remote - Multicolor 2.stl
13.1 x 9.12 x 0.565

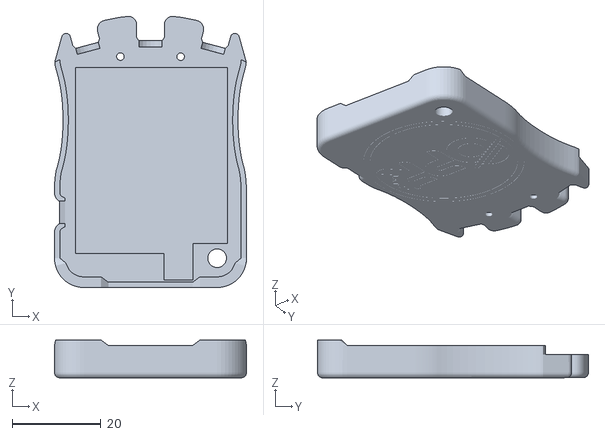
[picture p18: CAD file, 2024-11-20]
3d_model/Remote/IRStart - Remote case with Logo round/IRstart Remote - Single.stl
43.2 x 61.0 x 8.50

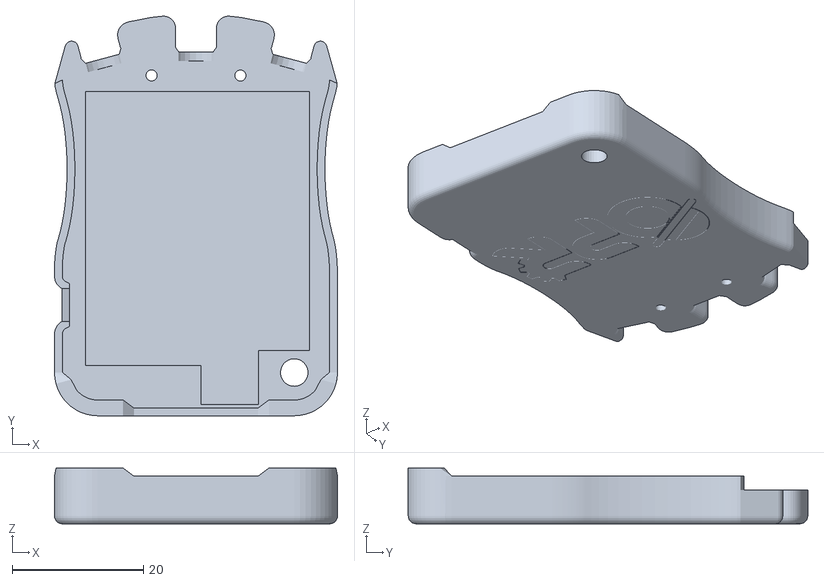
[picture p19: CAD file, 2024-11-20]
3d_model/Remote/IRStart - Remote case with Logo/IRstart Remote - Single.stl
43.2 x 61.0 x 8.50

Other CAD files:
3d_model/Remote/IRStart - Remote case with Logo round/IRStart Remote - Multicolor 1.stl
3d_model/Remote/IRStart - Remote case with Logo/IRStart Remote - Multicolor 5.stl
3d_model/Remote/IRStart - Remote case with Logo/IRStart Remote - Multicolor 4.stl
3d_model/Remote/IRStart - Remote case with Logo/IRStart Remote - Multicolor 3.stl
3d_model/Module/IRStart - Module.stl
3d_model/Remote/sketchup/IRstart - Remote.dwg

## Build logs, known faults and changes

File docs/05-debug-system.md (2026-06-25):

# Sistema de Debug

El sistema IRStart ofrece capacidades de debug mediante salida serie en el
mando y patrones de LEDs en ambos dispositivos.

---

## Salida Serie (Remote)

| Parámetro | Valor |
|---|---|
| **Interfaz** | USB CDC Serial |
| **Baudrate** | 115200 baud |
| **Función** | `Serial` (Arduino) |

### Función `debug_all()`

[`debug.cpp:3-33`](../source_code/Remote/src/debug.cpp)

La función `debug_all()` imprime el estado de todas las entradas digitales.
Está definida pero **no se llama desde `loop()`** — requiere descomentar la
llamada en [`main.cpp:29`](../source_code/Remote/src/main.cpp#L29) para
activarla:

```cpp
// debug_all();  // Descomentar para activar
```

**Formato de salida:**

```
BTN_START: 0 | BTN_STOP: 0 | BTN_READY: 0 | DIP_SW0: 0 | DIP_SW1: 0 | DIP_SW2: 0 | DIP_SW3: 0
```

| Campo | Descripción |
|---|---|
| `BTN_START` | Estado del botón Start (GPIO 21) |
| `BTN_STOP` | Estado del botón Stop (GPIO 20) |
| `BTN_READY` | Estado del botón Ready (GPIO 10) |
| `DIP_SW0` | DIP switch posición 0 (GPIO 0) |
| `DIP_SW1` | DIP switch posición 1 (GPIO 1) |
| `DIP_SW2` | DIP switch posición 2 (GPIO 2) |
| `DIP_SW3` | DIP switch posición 3 (GPIO 3) |

> **Nota**: `debug_all()` también activa momentáneamente el LED onboard y el
> PWM del IR_CMD a 1/3 de duty cycle durante cada iteración.

## LEDs de Información (Remote)

| LED | Color/Patrón | Significado |
|-----|---|---|
| **LED onboard** | Fijo | Mando encendido (se enciende en `init_components()`) |
| **LED onboard** | Parpadeo en boot | Esperando liberación de botones |
| **LED onboard** | Parpadeo rápido ×3 | Error de protocolo (`error_led()`) |
| **NeoPixel 0** | Verde | Modo IRSTART — Ready activo |
| **NeoPixel 0** | Apagado | Modo IRMENU |
| **NeoPixel 1** | Rojo | Modo IRSTART — Start activo |
| **NeoPixel 1** | Apagado | Modo IRMENU |
| **NeoPixel 2** | Magenta | Modo IRSTART — Stop activo |
| **NeoPixel 2** | Azul | Modo IRMENU |

### Patrón `error_led()`

[`io.cpp:25-34`](../source_code/Remote/src/io.cpp)

Secuencia de 3 pulsos cortos (50 ms ON/OFF) seguidos de pausa de 250 ms.
Se activa al usar un protocolo o comando no implementado en el modo actual.

## LEDs de Información (Module)

| LED | Patrón | Significado |
|-----|---|---|
| **LED azul** | Fijo | Módulo started (carrera en curso) |
| **LED azul** | Parpadeo alternante | Módulo stopped (en espera) |
| **LED azul** | 5 parpadeos acelerados | Feedback de programación exitosa |

### Parpadeo en Espera

[`main.cpp:14-26`](../source_code/Module/src/main.cpp)

En estado stopped, el LED alterna con duty cycle asimétrico: ~100ms ON,
~1600ms OFF. Esto proporciona información visual de que el módulo está
alimentado y en espera sin consumir corriente excesiva.

### Feedback de Programación

[`control.cpp:21-29`](../source_code/Module/src/control.cpp)

```cpp
void module_feedback() {
    for (uint8_t i = 0; i < 5; i++) {
        digitalWrite(PIN_LED, HIGH);
        delay(80 - (15 * i));   // 80, 65, 50, 35, 20 ms
        digitalWrite(PIN_LED, LOW);
        delay(80 - (15 * i));
    }
    delay(1500);
}
```

Cinco parpadeos de frecuencia creciente (de 80 ms a 20 ms), seguidos de
una pausa de 1.5 segundos. Se ejecuta en el contexto de la ISR al recibir
un comando de programación válido.

> **⚠️ Advertencia**: Esta función se ejecuta desde la ISR del receptor IR a
> través de `rc5_manage_command()`. Contiene múltiples `delay()` que bloquean
> las interrupciones durante ~2 segundos. Ver [SW-02](07-known-issues.md#sw-02).

---

*Documento generado el 2025-06-25. Ver también [Arquitectura Software](02-software-architecture.md), [Menú](04-menu-system.md), [Problemas Conocidos](07-known-issues.md).*

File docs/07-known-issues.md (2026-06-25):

# Problemas Conocidos

> **Fecha de análisis**: 2025-06-25
> **Última actualización**: 2025-06-25
> **Commit**: `e274009`
> **Total**: 10 issues — 3 críticos, 4 moderados, 3 leves

---

## Correcciones Recientes ✅

| ID | Fecha | Descripción |
|----|---|---|
| — | — | — |

---

## 🔴 Críticos

#### SW-01 — `delayMicroseconds(100)` en contexto de ISR

- **Archivo**: [`rc5.cpp:102`](../source_code/Module/src/rc5.cpp#L102)
- **Descripción**: La función `rc5_register()` contiene una llamada a
  `delayMicroseconds(100)` en el flujo de la ISR `rc5_isr()`. En un ATtiny
  a 1.2 MHz, esto bloquea las interrupciones durante 100 µs, equivalente a
  ~120 ciclos de CPU desperdiciados. Cualquier otra interrupción (incluyendo
  más flancos del receptor IR) se pierde durante este tiempo.
- **Impacto**: **Alto** — Puede causar pérdida de pulsos IR y decodificación
  incorrecta de tramas RC5, especialmente en entornos con ruido IR.
- **Mitigación actual**: Ninguna. La llamada está incondicionalmente en la
  ruta de la ISR.
- **Solución propuesta**: Eliminar el `delayMicroseconds(100)` o mover la
  lógica de decodificación a un buffer procesado en `loop()`.

#### SW-02 — `EEPROM.write()` en contexto de ISR

- **Archivo**: [`rc5.cpp:30-31`](../source_code/Module/src/rc5.cpp#L30-L31)
- **Descripción**: `rc5_manage_command()` (llamada desde la ISR
  `rc5_isr()` → `rc5_register()`) ejecuta `EEPROM.write()` cuando recibe un
  comando de programación (ADDRESS_PROG). La escritura en EEPROM del ATtiny
  tarda ~3.3 ms y **deshabilita todas las interrupciones** durante la
  operación. Además, `module_feedback()` añade ~2 s adicionales de delays
  dentro del contexto de ISR.
- **Impacto**: **Alto** — El sistema queda completamente ciego durante la
  programación (~2 s). Si llegan comandos IR durante este tiempo, se pierden.
- **Mitigación actual**: Ninguna. La programación ocurre en línea dentro de la ISR.
- **Solución propuesta**: Marcar un flag en la ISR (`volatile bool
  pending_program`) y procesar la escritura en EEPROM + feedback en `loop()`.

#### SW-03 — Variable `started` sin calificador `volatile`

- **Archivo**: [`control.cpp:3`](../source_code/Module/src/control.cpp#L3)
- **Descripción**: La variable `static bool started` es modificada por
  `module_start()` y `module_stop()`, que se llaman desde la ISR a través de
  `rc5_manage_command()`. También es leída por `module_is_started()` desde
  `loop()`. Sin `volatile`, el compilador puede optimizar la lectura en
  `loop()` cacheando el valor en un registro y no detectando cambios.
- **Impacto**: **Alto** — El módulo podría no reflejar cambios de estado
  start/stop correctamente si el compilador optimiza el acceso. En AVR con
  optimización baja (-Os) el bug puede no manifestarse, pero es frágil.
- **Mitigación actual**: Ninguna. Depende del nivel de optimización del compilador.
- **Solución propuesta**: Declarar `static volatile bool started = false;`.

---

## 🟡 Moderados

#### SW-04 — Gap de histéresis insuficiente en detección de pulsos RC5

- **Archivo**: [`rc5.h:21-24`](../source_code/Module/include/rc5.h#L21-L24)
- **Descripción**: Las constantes de detección de pulsos RC5 tienen solo 1 µs
  de separación entre corto y largo: `MAX_SHORT = 1333`, `MIN_LONG = 1334`.
  El estándar RC5 usa 889 µs para medio bit corto y 1778 µs para largo. Con
  tolerancia de reloj del RC interno del ATtiny (±10% a 1.2 MHz), un pulso
  nominal de 889 µs podría medirse como 978 µs (dentro del rango corto) o
  1334 µs (clasificado incorrectamente como largo).
- **Impacto**: **Medio** — Puede causar errores de decodificación con
  variaciones de temperatura o voltaje que afecten al oscilador interno.
- **Mitigación actual**: Ninguna.
- **Solución propuesta**: Ajustar los umbrales con un gap de al menos 100-200 µs:
  `MAX_SHORT = 1200`, `MIN_LONG = 1400`, o usar el punto medio entre 889 y
  1778 (1333 µs) como umbral único.

#### HW-01 — `BAT_ANALOG` definido pero sin implementar

- **Archivo**: [`pinout.h:6`](../source_code/Remote/include/pinout.h#L6)
- **Descripción**: El pin GPIO 2 está definido como `BAT_ANALOG` para lectura
  del voltaje de batería, pero no existe ningún código que lea el ADC ni
  muestre el estado de la batería. Además, GPIO 2 se usa simultáneamente como
  `DIP_SW_2`, creando un conflicto de funciones si se implementara la lectura.
- **Impacto**: **Medio** — La funcionalidad de monitorización de batería está
  ausente. El usuario no recibe aviso de batería baja. El conflicto de pines
  requeriría un rediseño del PCB o usar un pin diferente para el ADC.
- **Mitigación actual**: Ninguna.
- **Solución propuesta**: Elegir un pin libre para BAT_ANALOG (ej. GPIO 3,
  actualmente DIP_SW_3, o reasignar DIP switches) e implementar la lectura
  periódica del ADC con un divisor de tensión.

#### PR-01 — Include circular en `ir.h`

- **Archivo**: [`ir.h:4`](../source_code/Remote/include/ir.h#L4)
- **Descripción**: El archivo `ir.h` contiene `#include <ir.h>` — se incluye
  a sí mismo. Aunque los include guards (`#ifndef IR_H`) evitan la recursión
  infinita, esto es un error que indica posiblemente una intención de incluir
  otro archivo (quizás `io.h` o `config.h`).
- **Impacto**: **Medio** — No causa fallos funcionales gracias a los include
  guards, pero es un code smell y podría confundir a desarrolladores o
  herramientas de análisis estático.
- **Mitigación actual**: Los include guards evitan el fallo.
- **Solución propuesta**: Eliminar `#include <ir.h>` de `ir.h`.

#### SW-05 — Bucles busy-wait bloquean actualización de LEDs

- **Archivo**: [`main.cpp:34-35`](../source_code/Remote/src/main.cpp#L34-L35)
- **Descripción**: En `loop()`, tras enviar un comando IR, hay bucles
  `while (get_btn_ready()) {}` que esperan a que el usuario suelte el botón.
  Durante esta espera, el código de actualización de NeoPixels al final del
  loop no se ejecuta, por lo que los LEDs quedan congelados.
- **Impacto**: **Medio** — Mala experiencia de usuario (LEDs congelados al
  mantener pulsado un botón). No es crítico para la funcionalidad IR.
- **Mitigación actual**: Ninguna.
- **Solución propuesta**: Usar una máquina de estados con `static bool
  button_was_pressed` y `millis()` para anti-rebote sin bloquear el loop.
  Así los NeoPixels se actualizan incluso con botones pulsados.

---

## 🟢 Leves

#### MN-01 — Comando de programación inconsistente para `id=0`

- **Archivo**: [`rc5.cpp:87-91`](../source_code/Remote/src/rc5.cpp#L87-L91)
- **Descripción**: `rc5_send_prog()` envía el comando `0x01` cuando `id == 0`,
  pero para `id != 0` envía `id << 1`. Con `id = 0`, `id << 1 = 0`, así que
  los patrones no coinciden. El receptor interpreta `command` como STOP y
  `command + 1` como START. Con `id = 0`, `command = 0x01`, por lo que
  START = 0x02 y STOP = 0x01. Esto funciona pero es un caso especial
  inconsistente con el resto de IDs.
- **Impacto**: **Bajo** — Funciona correctamente pero añade complejidad
  innecesaria y dificulta el mantenimiento.
- **Mitigación actual**: Ninguna necesaria.
- **Solución propuesta**: Unificar la lógica para que `id = 0` siga el mismo
  patrón `id << 1`, o documentar explícitamente que `id = 0` es un caso
  especial.

#### PR-02 — Inconsistencia en lógica de repetición NEC vs SIRC

- **Archivo**: [`nec.cpp:53-68`](../source_code/Remote/src/nec.cpp#L53-L68)
  vs [`sirc.cpp:46-68`](../source_code/Remote/src/sirc.cpp#L46-L68)
- **Descripción**: NEC implementa un sistema de repetición de comando: si el
  mismo comando se reenvía dentro de la ventana `CMD_WAIT_MS + 50`, se usa
  `send_repeat()` (código de repetición NEC). SIRC no tiene esta lógica y
  reenvía la trama completa cada `CMD_WAIT_MS` (45 ms). La diferencia refleja
  las especificaciones de cada protocolo, pero el código de repetición de NEC
  es más complejo sin documentar el razonamiento.
- **Impacto**: **Bajo** — Ambos protocolos funcionan. La complejidad adicional
  en NEC podría ocultar bugs sutiles en el timing.
- **Mitigación actual**: Ninguna necesaria.
- **Solución propuesta**: Documentar la lógica de repetición en NEC o
  simplificarla.

#### DB-01 — Código comentado sin limpiar

- **Archivos**: [`main.cpp:23-25`](../source_code/Module/src/main.cpp#L23-L25),
  [`rc5.cpp:90-96`](../source_code/Module/src/rc5.cpp#L90-L96),
  [`rc5.cpp:115-121`](../source_code/Module/src/rc5.cpp#L115-L121)
- **Descripción**: Hay bloques de código comentado que implementan
  funcionalidad de reset de EEPROM y un método alternativo de lectura RC5
  por polling (`rc5_update()`). El código comentado sugiere funcionalidad
  planificada pero no implementada, lo que puede confundir.
- **Impacto**: **Bajo** — No afecta al funcionamiento.
- **Mitigación actual**: Ninguna.
- **Solución propuesta**: Eliminar el código comentado o implementar las
  funcionalidades pendientes (reset de EEPROM con protección).

---

*Documento generado el 2025-06-25. Issues detectados mediante auditoría manual del código fuente durante `doc-init`. Para actualizar tras cambios de código, usar `/doc-review`.*

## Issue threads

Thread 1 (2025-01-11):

Código Cargar Modulo

FSebaT, 2025-01-11:
Buenas Tardes ! Primero que nada muy buen proyecto, me interesaria saber que o cual código debo cargarle al ATTYNI13, veo que hay varios archivos por eso no se cual sería el correcto.
Muchas Gracias

robotaleh, 2025-01-12:
Buenas!
El proyecto está pensado para compilarse fácilmente mediante VSCode con PlatformIO. Si abres el directorio **source_code/Module/** con VSCode verás que en la parte inferior puedes seleccionar la "placa destino" para la compilación. Ahí marcas ATTINY13 y ya lo tienes.
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

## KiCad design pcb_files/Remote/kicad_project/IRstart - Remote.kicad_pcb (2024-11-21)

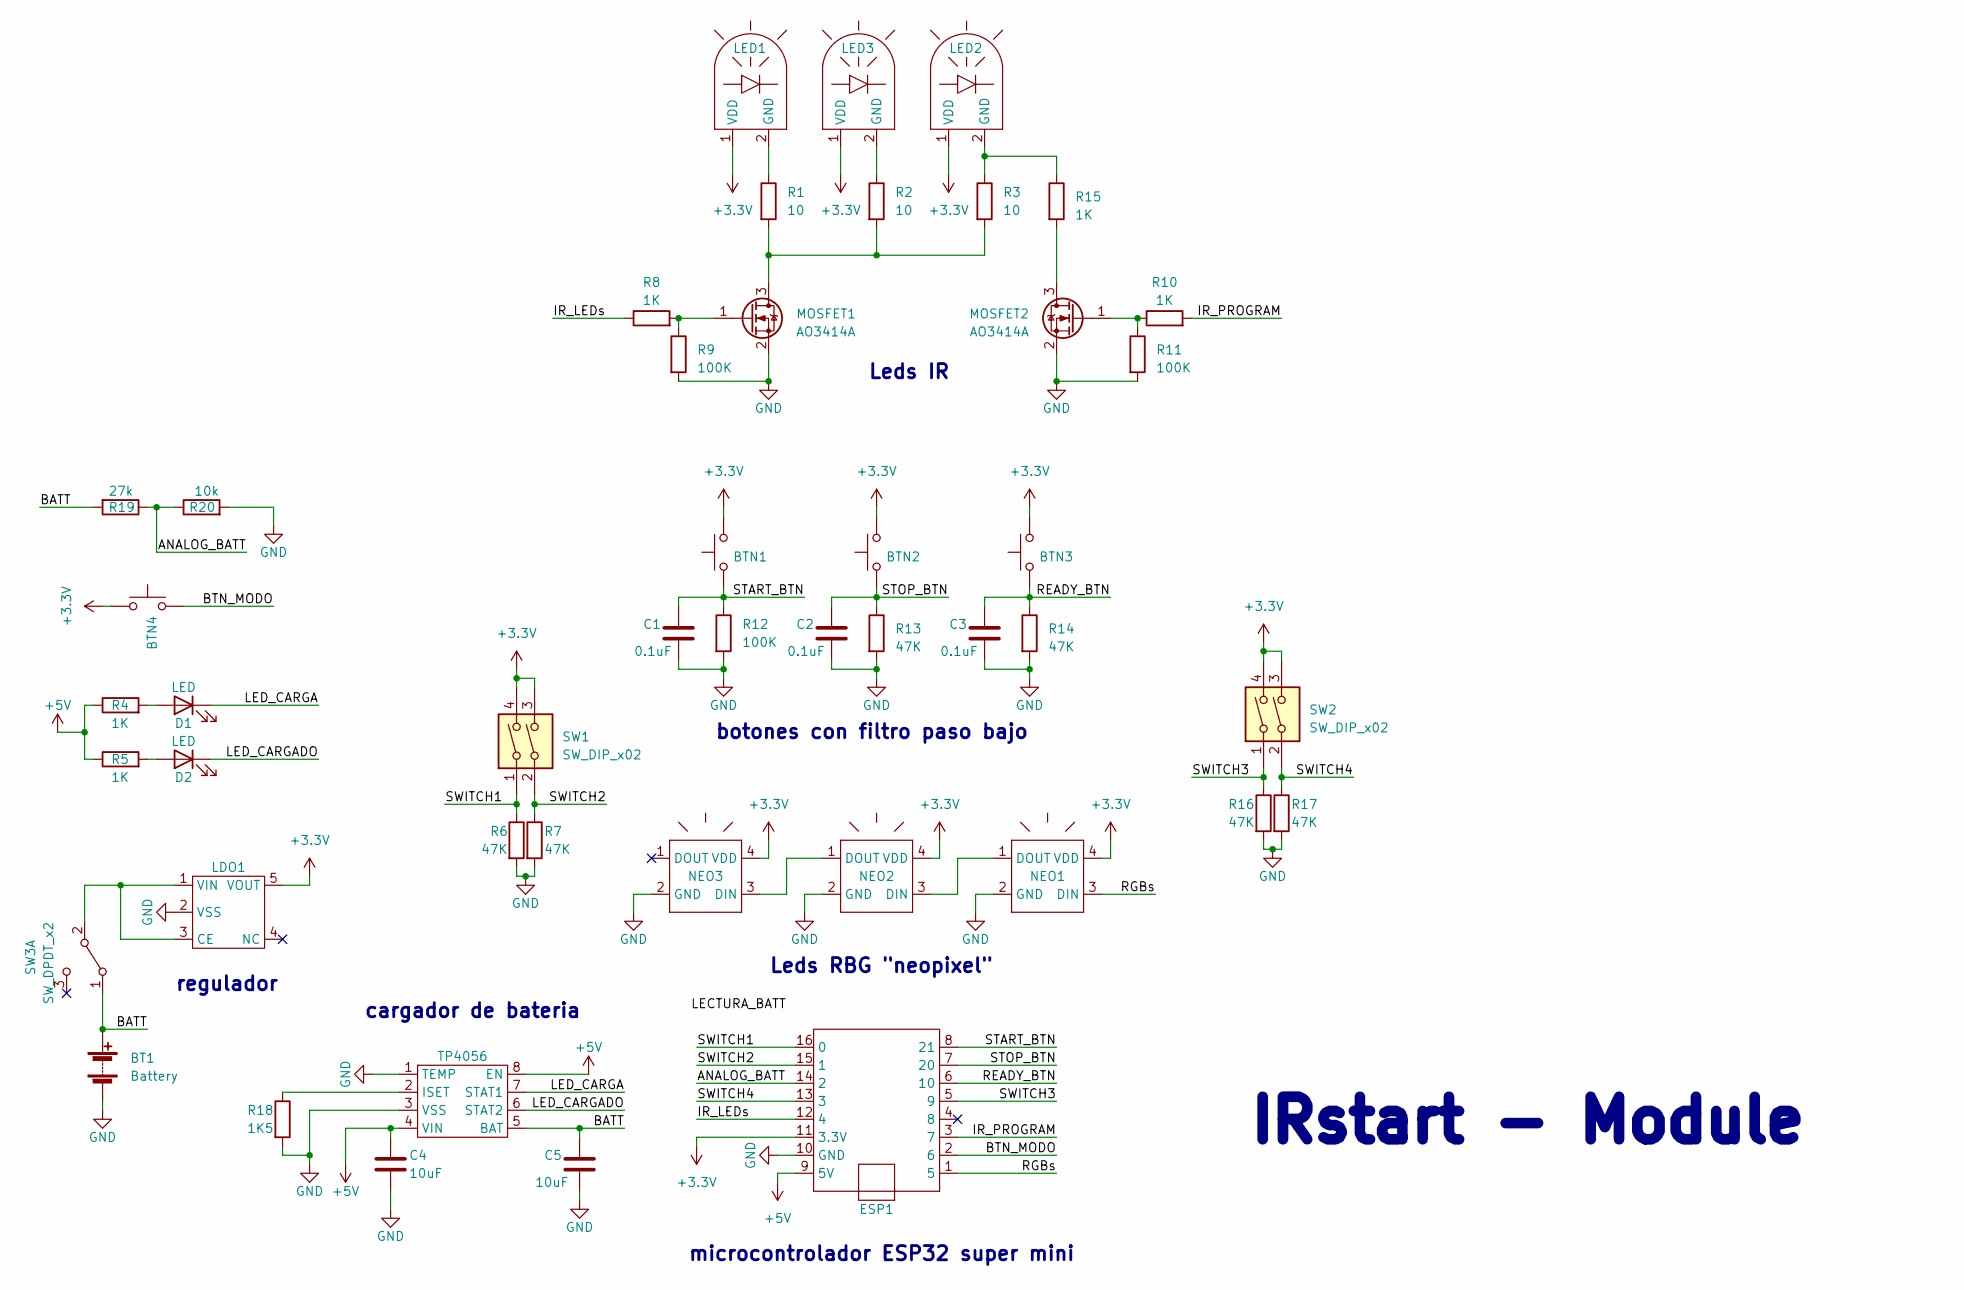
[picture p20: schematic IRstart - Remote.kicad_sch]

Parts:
BT1: Battery; Leds_IR_Remote
BTN1, BTN2, BTN3: SW_Push_1P1T_NO_6x6mm_H9.5mm
BTN4: SW_SPST_B3U-1000P
C1, C2, C3: 0.1uF; C_0805_2012Metric_Pad1.18x1.45mm_HandSolder
C4, C5: 10uF; C_0805_2012Metric_Pad1.18x1.45mm_HandSolder
D1, D2: LED; LED_0805_2012Metric_Pad1.15x1.40mm_HandSolder
ESP1: ESP32_supermini
LDO1: SOT-23-5_HandSoldering
LED1, LED2, LED3: Leds_IR_Remote
MOSFET1, MOSFET2: AO3414A; SOT-23
NEO1, NEO2, NEO3: LED_WS2812B_2.0x2.0mm
R1, R2, R3: 10; R_0805_2012Metric_Pad1.20x1.40mm_HandSolder
R4, R5, R8, R10, R15: 1K; R_0805_2012Metric_Pad1.20x1.40mm_HandSolder
R6, R7, R13, R14, R16, R17: 47K; R_0805_2012Metric_Pad1.20x1.40mm_HandSolder
R9, R11, R12: 100K; R_0805_2012Metric_Pad1.20x1.40mm_HandSolder
R18: 1K5; R_0805_2012Metric_Pad1.20x1.40mm_HandSolder
R19: 27k; R_0805_2012Metric_Pad1.20x1.40mm_HandSolder
R20: 10k; R_0805_2012Metric_Pad1.20x1.40mm_HandSolder
SW1, SW2: SW_DIP_x02; SW_DIP_SPSTx02_Slide_6.7x6.64mm_W8.61mm_P2.54mm_LowProfile
SW3: SW_DPDT_x2; SW_SPDT_PCM12
TP4056: SOP-8_3.9x4.9mm_P1.27mm

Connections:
+3.3V: BTN1.2, BTN2.2, BTN3.2, BTN4.2, ESP1.11 (3.3V), LDO1.5 (VOUT), LED1.1 (VDD), LED2.1 (VDD), LED3.1 (VDD), NEO1.4 (VDD), NEO2.4 (VDD), NEO3.4 (VDD), SW1.3, SW1.4, SW2.3, SW2.4
+5V: C4.1, ESP1.9 (5V), R4.1, R5.1, TP4056.4 (VIN), TP4056.8 (EN)
/ANALOG_BATT: ESP1.14 (2), R19.1, R20.1
/BATT: BT1.1 (+), C5.1, R19.2, SW3.1 (A), TP4056.5 (BAT)
/BTN_MODO: BTN4.1, ESP1.2 (6)
/IR_LEDs: ESP1.12 (4), R8.1
/IR_PROGRAM: ESP1.3 (7), R10.2
/LED_CARGA: D1.1 (K), TP4056.7 (STAT1)
/LED_CARGADO: D2.1 (K), TP4056.6 (STAT2)
/READY_BTN: BTN3.1, C3.1, ESP1.6 (10), R14.1
/RGBs: ESP1.1 (5), NEO1.3 (DIN)
/START_BTN: BTN1.1, C1.1, ESP1.8 (21), R12.1
/STOP_BTN: BTN2.1, C2.1, ESP1.7 (20), R13.1
/SWITCH1: ESP1.16 (0), R6.1, SW1.1
/SWITCH2: ESP1.15 (1), R7.1, SW1.2
/SWITCH3: ESP1.5 (9), R16.1, SW2.1
/SWITCH4: ESP1.13 (3), R17.1, SW2.2
GND: BT1.2 (-), C1.2, C2.2, C3.2, C4.2, C5.2, ESP1.10 (GND), LDO1.2 (VSS), MOSFET1.2 (S), MOSFET2.2 (S), NEO1.2 (GND), NEO2.2 (GND), NEO3.2 (GND), R6.2, R7.2, R9.2, R11.2, R12.2, R13.2, R14.2, R16.2, R17.2, R18.2, R20.2, TP4056.1 (TEMP), TP4056.3 (VSS)
unnamed: D1.2 (A), R4.2
unnamed: D2.2 (A), R5.2
unnamed: LDO1.1 (VIN), LDO1.3 (CE), SW3.2 (B)
unnamed: LED1.2 (GND), R1.1
unnamed: LED2.2 (GND), R3.1, R15.1
unnamed: LED3.2 (GND), R2.1
unnamed: MOSFET1.3 (D), R1.2, R2.2, R3.2
unnamed: MOSFET1.1 (G), R8.2, R9.1
unnamed: MOSFET2.3 (D), R15.2
unnamed: MOSFET2.1 (G), R10.1, R11.1
unnamed: NEO1.1 (DOUT), NEO2.3 (DIN)
unnamed: NEO2.1 (DOUT), NEO3.3 (DIN)
unnamed: R18.1, TP4056.2 (ISET)

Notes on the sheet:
IRstart - Module
cargador de bateria
Leds IR
Leds RBG "neopixel"
regulador
microcontrolador ESP32 super mini
botones con filtro paso bajo

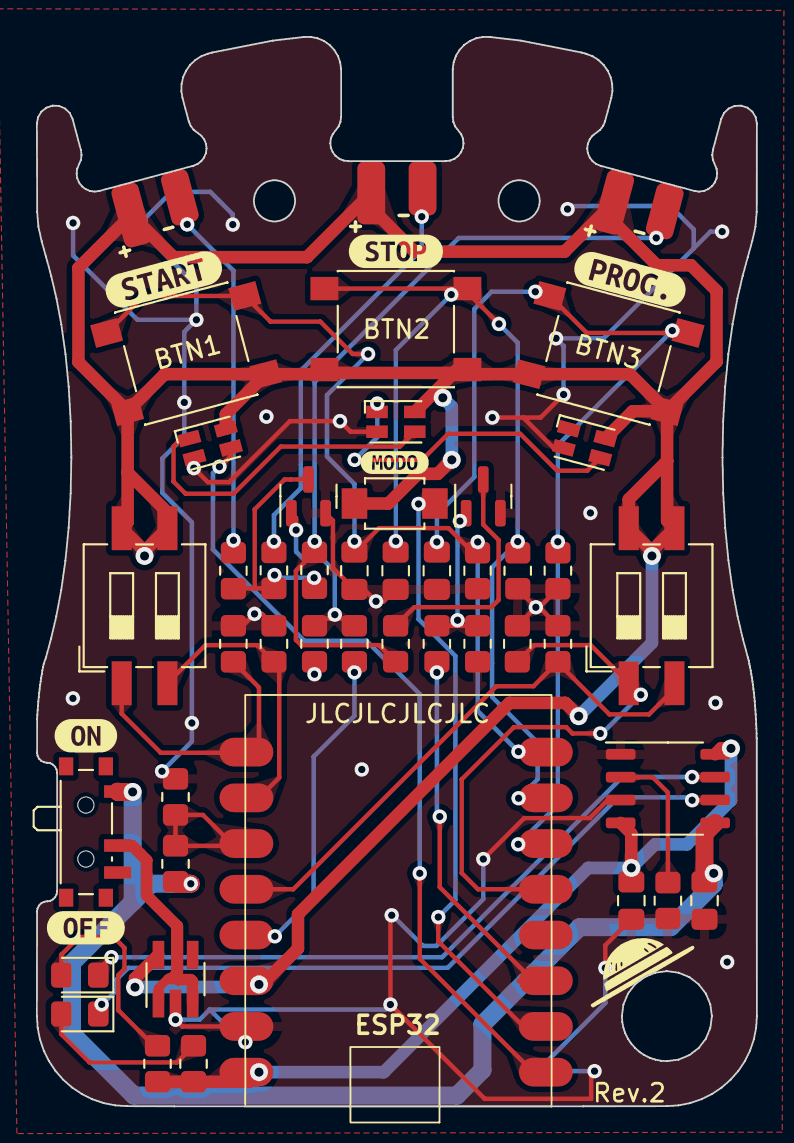
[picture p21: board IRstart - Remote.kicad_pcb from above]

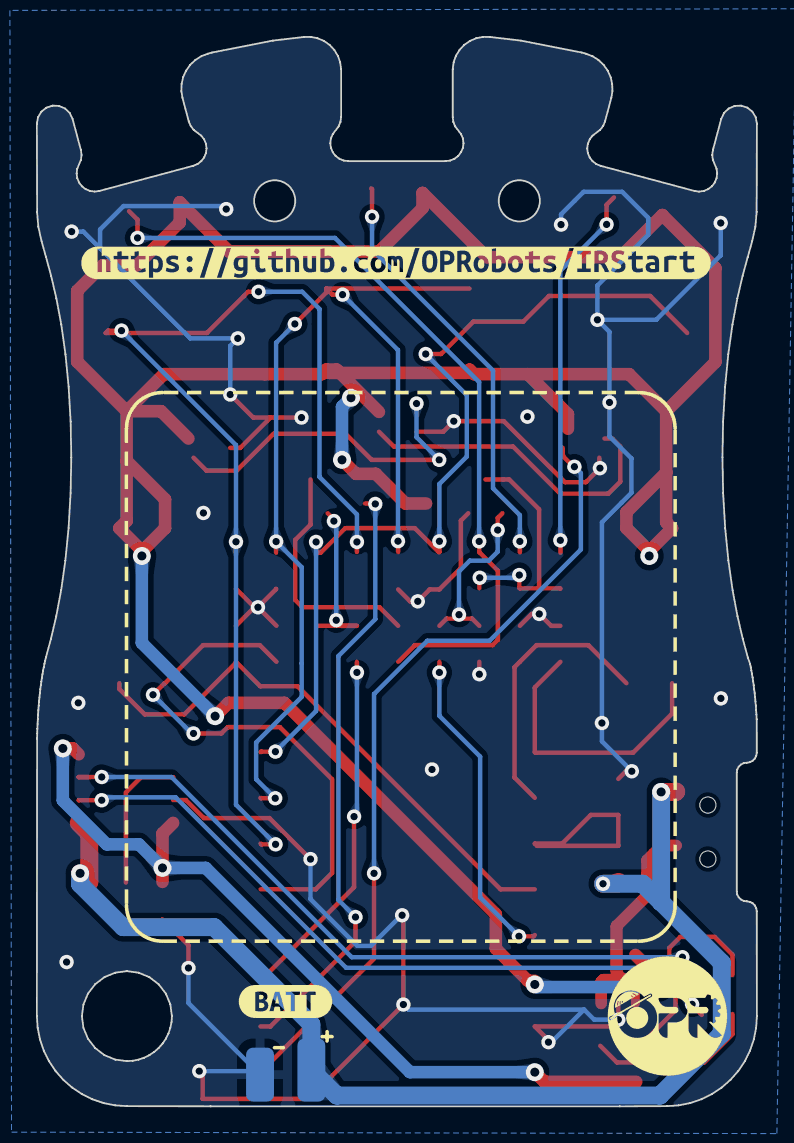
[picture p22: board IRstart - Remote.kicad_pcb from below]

Board: 2 copper layers, 40.0 x 59.4 mm, 54 parts (3 on the bottom side), 31 nets.

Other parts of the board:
kibuzzard-664F31E4: G***; kibuzzard-664F31E4
kibuzzard-673F80D1: G***; kibuzzard-673F80D1
kibuzzard-673F8949: G***; kibuzzard-673F8949
kibuzzard-673F8963: G***; kibuzzard-673F8963
kibuzzard-6637BAEA: G***; kibuzzard-6637BAEA
kibuzzard-6637BBE8: G***; kibuzzard-6637BBE8
kibuzzard-6637BC1A: G***; kibuzzard-6637BC1A
kibuzzard-6637DAEE: G***; kibuzzard-6637DAEE

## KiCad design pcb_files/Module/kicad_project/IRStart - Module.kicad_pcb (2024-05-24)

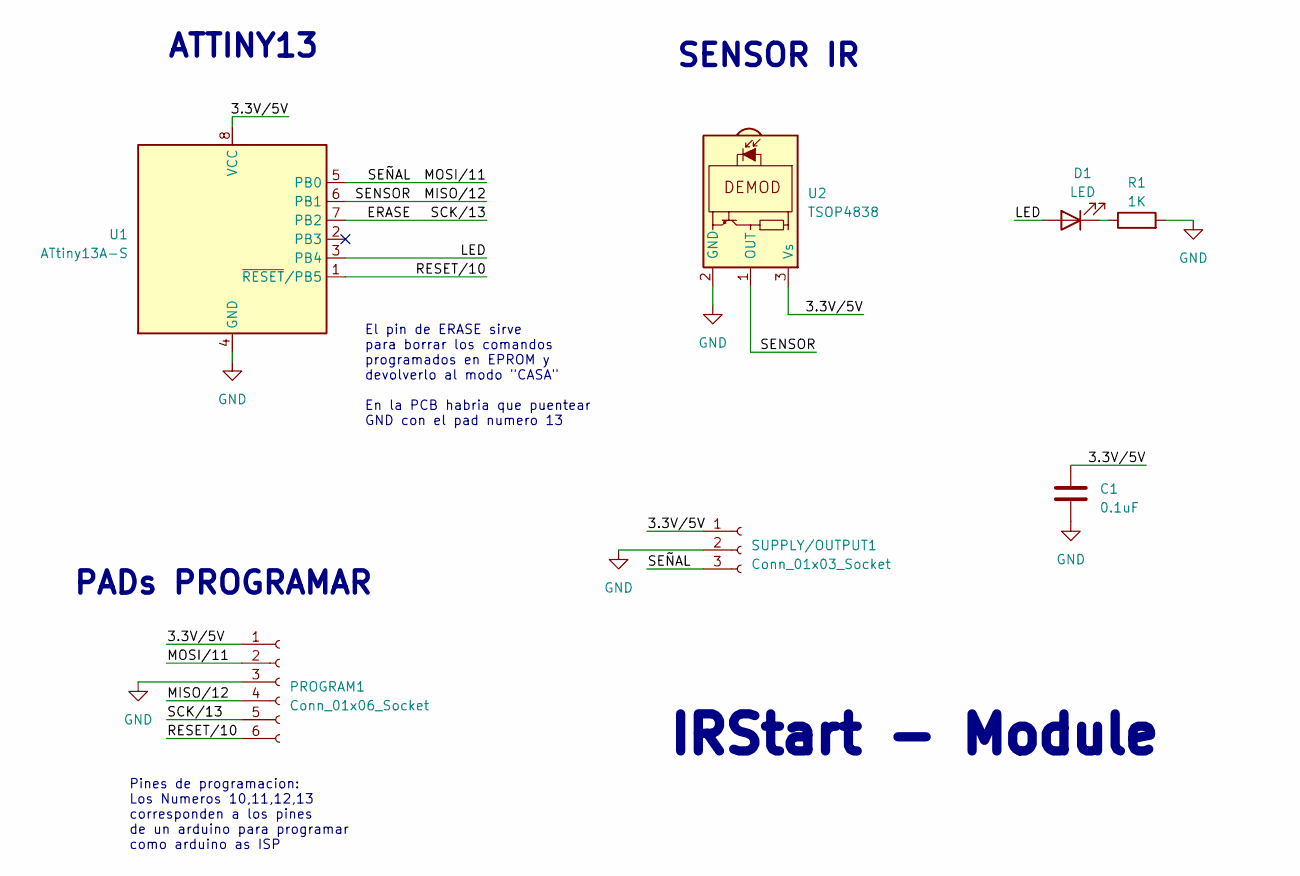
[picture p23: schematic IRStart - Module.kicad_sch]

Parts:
C1: 0.1uF; C_0402_1005Metric_Pad0.74x0.62mm_HandSolder
D1: LED; LED_0805_2012Metric
PROGRAM1: Conn_01x06_Socket; Program_pads
R1: 1K; R_0805_2012Metric
SUPPLY/OUTPUT1: Conn_01x03_Socket; PinSocket_1x03_P2.54mm_Vertical
U1: ATtiny13A-S; SOP8
U2: TSOP4838; Vishay_MOLD-3Pin

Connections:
/3.3V/5V: C1.1, PROGRAM1.1, SUPPLY/OUTPUT1.1, U1.8 (VCC), U2.3 (Vs)
/ERASE: PROGRAM1.5, U1.7 (PB2)
/LED: D1.2 (A), U1.3 (PB4)
/MISO/12: PROGRAM1.4, U1.6 (PB1), U2.1 (OUT)
/MOSI/11: PROGRAM1.2, SUPPLY/OUTPUT1.3, U1.5 (PB0)
/RESET/10: PROGRAM1.6, U1.1 (~RESET/PB5)
GND: C1.2, PROGRAM1.3, R1.2, SUPPLY/OUTPUT1.2, U1.4 (GND), U2.2 (GND)
unnamed: D1.1 (K), R1.1

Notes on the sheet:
SENSOR IR
PADs PROGRAMAR
El pin de ERASE sirve para borrar los comandos programados en EPROM y devolverlo al modo "CASA" En la PCB habria que puentear GND con el pad numero 13
ATTINY13
IRStart - Module
Pines de programacion: Los Numeros 10,11,12,13 corresponden a los pines de un arduino para programar como arduino as ISP

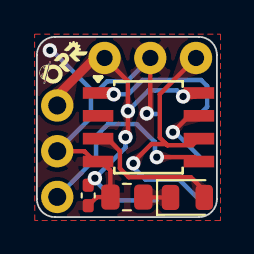
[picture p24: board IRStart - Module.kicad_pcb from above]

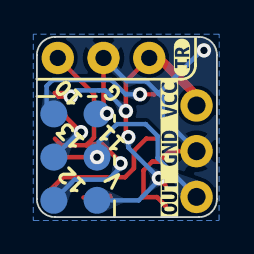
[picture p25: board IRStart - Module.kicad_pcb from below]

Board: 2 copper layers, 10.0 x 10.0 mm, 9 parts (3 on the bottom side), 8 nets.

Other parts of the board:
kibuzzard-664B9D8E: G***; kibuzzard-664B9D8E
kibuzzard-664B97EA: G***; kibuzzard-664B97EA

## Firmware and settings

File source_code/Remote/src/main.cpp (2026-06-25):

#include <Arduino.h>

#include <config.h>
#include <debug.h>
#include <io.h>
#include <ir.h>

PROTOCOL protocol = RC5;

void setup() {
  init_components();
  if (get_btn_start()) {
    protocol = RC5;
  } else if (get_btn_stop()) {
    protocol = NEC;
  } else if (get_btn_ready()) {
    protocol = SIRC;
  }
  init_ir(protocol);
  while (get_btn_ready() || get_btn_start() || get_btn_stop()) {
    blink_led(500);
  }
  set_rgb(0, 50, 0, 0);
  set_rgb(1, 0, 50, 0);
  set_rgb(2, 0, 0, 50);
}

void loop() {
  // debug_all();
  if (get_btn_ready()) {
    do {
      send_ready(protocol);
    } while (get_btn_ready() && get_mode() == IRSTART);
    while (get_btn_ready()) {
    }
  }

  if (get_btn_start()) {
    do {
      send_start(protocol);
    } while (get_btn_start() && get_mode() == IRSTART);
    while (get_btn_start()) {
    }
  }

  if (get_btn_stop()) {
    do {
      send_stop(protocol);
    } while (get_btn_stop() && get_mode() == IRSTART);
    while (get_btn_stop()) {
    }
  }

  while (get_btn_stop()) {
    send_stop(protocol);
  }

  if (get_btn_mode()) {
    while (get_btn_mode()) {
    }
    set_mode((MODE)((get_mode() + 1) % NUM_MODES));
  }

  switch (get_mode()) {
    case IRSTART:
      set_rgb(0, 0, 50, 0);
      set_rgb(1, 50, 0, 0);
      set_rgb(2, 50, 0, 50);
      break;
    case IRMENU:
      set_rgb(0, 0, 0, 0);
      set_rgb(1, 0, 0, 0);
      set_rgb(2, 0, 0, 50);
      break;
    default:
      set_rgb(0, 50, 0, 0);
      set_rgb(1, 50, 0, 0);
      set_rgb(2, 50, 0, 0);
      break;
  }
}

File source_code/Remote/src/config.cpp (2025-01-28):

#include <config.h>

void init_components() {
  Serial.begin(115200);

  pinMode(LED, OUTPUT);
  digitalWrite(LED, HIGH);

  pinMode(NEOPIXEL, OUTPUT);

  pinMode(IR_CMD, OUTPUT);
  digitalWrite(IR_CMD, LOW);

  pinMode(IR_PROG, OUTPUT);
  digitalWrite(IR_PROG, LOW);

  pinMode(BTN_START, INPUT);
  pinMode(BTN_STOP, INPUT);
  pinMode(BTN_READY, INPUT);
  pinMode(BTN_MODE, INPUT_PULLDOWN);

  pinMode(DIP_SW_0, INPUT);
  pinMode(DIP_SW_1, INPUT);
  pinMode(DIP_SW_2, INPUT);
  pinMode(DIP_SW_3, INPUT);
}

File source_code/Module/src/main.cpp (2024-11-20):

#include "control.h"
#include "pinout.h"
#include "rc5.h"
#include <Arduino.h>

bool led_state = false;

void setup(void) {
  init_pinout();
  rc5_init();
}

void loop(void) {
  if (module_is_started()) {
    digitalWrite(PIN_LED, HIGH);
  } else {
    digitalWrite(PIN_LED, led_state = !led_state);
    uint16_t count = 0;
    while (((led_state && count <= 100) || (!led_state && count <= 1600)) && !module_is_started()) {
      count++;
      delay(1);
    }
    // if (!digitalRead(PIN_RESET)) {
    //   rc5_reset_eeprom();
    // }
  }
}

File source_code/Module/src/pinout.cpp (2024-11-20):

#include "pinout.h"

void init_pinout(void) {
  pinMode(PIN_IR, INPUT);
  pinMode(PIN_SIGNAL, OUTPUT);
  pinMode(PIN_LED, OUTPUT);
  // pinMode(PIN_RESET, INPUT_PULLUP);

  attachInterrupt(digitalPinToInterrupt(PIN_IR), rc5_isr, CHANGE);
}

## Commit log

2023-08-18 Añade los ficheros del proyecto
    [IRStart_PCB.kicad_pcb, IRStart_PCB.sch]
2023-08-18 Actualiza readme añadiendo datos de Hardware e Imágenes
2024-04-21 Añade carpetas para IRstart - Remote y empieza el proyecto de kicad
    [IRStart_PCB.kicad_pcb, IRStart_PCB.sch, IRstart - Remote.kicad_pcb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]
2024-04-21 Avanza con el diseño del mando. Acaba esquema y ordena componentes PCB
    [IRstart - Remote.dwg, IRstart - Remote.dxf, IRstart - Remote.kicad_pcb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]
2024-05-05 Avanza con el diseño de la PCB
    [IRstart - Remote.kicad_pcb, IRstart - Remote.kicad_sch]
2024-05-23 Añade nuevos proyectos KiCad de Module y Remote y normaliza repo
    [IRStart - Module.kicad_pcb, IRStart - Module.kicad_sch, IRStart_PCB.kicad_pcb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]
2024-05-24 Añade gerbers de remote y adecenta el esquematico
    [IRStart - Module.step, IRstart - Remote.kicad_pcb, IRstart - Remote.kicad_sch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]
2024-05-24 Añade modelos 3D y pone bonito los "renders"
    [IRstart - Remote.kicad_pcb]
2024-05-24 Añade modelo 3D de TSOP4838 para el Module
    [IRStart - Module.kicad_pcb]
2024-06-12 Realiza los cambios necesarios para la PCB de IRStart
2024-06-19 Añade funcionamiento de RGBs
2024-06-19 Corrige leds RGB con huella incorrecta
    [IRstart - Remote.kicad_pcb, IRstart - Remote.kicad_sch, positions.csv]
2024-10-01 Añade imagines del diseño y de las PCBs montadas
2024-10-01 Añade imagen de mando y modulo montados
2024-10-01 Añade código del módulo para ATTiny13 y ATTiny85
2024-10-01 Actualiza recursos step y elimina imágenes antiguas
    [IRStart - Module.step]
2024-11-20 Añade diseños 3d y stls
    [IRStart - Module.step, IRStart - Module.stl, IRstart - Case remote with Logo round.stl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]
2024-11-21 Crea la Rev.2 del mando añadiendo boton de modo y lectura de bateria
    [IRstart - Remote.kicad_pcb, IRstart - Remote.kicad_sch, bom.csv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]
2025-01-28 Añade soporte para modo IRMENU
2026-06-25 Añalde ajustes antiguos para soporte a modo menú
2026-06-25 Añade STL de la carcasa del mando
    [IRStart Remote - Multicolor 1.stl, IRStart Remote - Multicolor 2.stl, IRStart Remote - Multicolor 3.stl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]
2026-06-25 Actualiza rutas de imágenes en documentación
2026-06-25 Actualiza enlaces de referencia de software
